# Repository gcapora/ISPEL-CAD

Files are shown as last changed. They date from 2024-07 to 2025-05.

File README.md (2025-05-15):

# Diseño de circuitos impresos del proyecto ISPEL

Autores: Guillermo Caporaletti y Alejandro Santari.
ISPEL Beta, Revisión 1.

En esta carpeta están los diseños de las placas del prototipo Beta 2024 de la Interfaz de Señales para Prácticas Educativas de Laboratorio (ISPEL). 

## Estructura de carpetas

- Docs: Incluye documentos de elaboración propia. Incluye listado de materiales.
- Info: Incluye bibliografía, hojas de datos, referencias y demás información que no es elaboración propia.
- PCB_Frente: PCB de botones y leds del frente del gabinete.
- PCB_Principal: PCB principal, sobre la cual va montada la placa Nuleao-144 de STM.

## Versiones

- Primera versión Beta corresponde al diseño presentado como parte del trabajo final de la Carrera de Especialización en Sistemas Embebidos de la FIUBA: [Versión 1 Beta](https://github.com/gcapora/ISPEL-CAD/releases/tag/v1-beta)

## Comentarios

- El diseño en PCB_Principal fue corregido tras construir el primer prototipo.
- Los archivos de PCB_Frente son orientativos y deben ser corregidos.

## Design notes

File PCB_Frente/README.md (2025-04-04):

Esta carpeta tiene el diseño de la placa de botones y leds del frente del gabinete, versión Beta 2024. El diseño es orientativo porque necesita una corrección importante.

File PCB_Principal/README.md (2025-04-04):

Aquí van los archivos del proyecto PLACA PRINCIPAL que incluye:
- Fuente y tensión de referencia
- Amplificadores
- Búferes de entrada
- Señal de prueba

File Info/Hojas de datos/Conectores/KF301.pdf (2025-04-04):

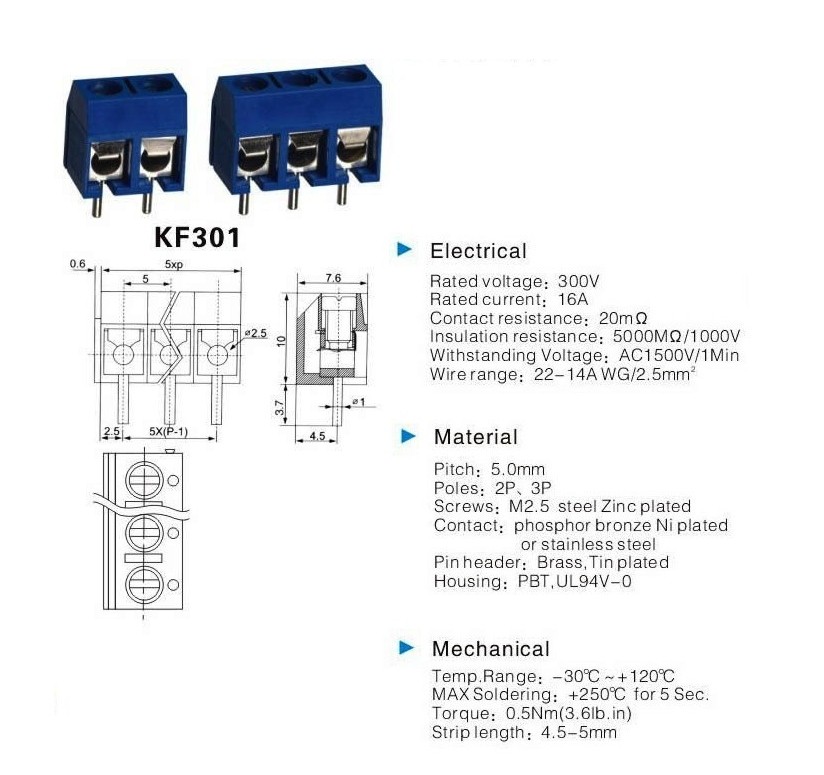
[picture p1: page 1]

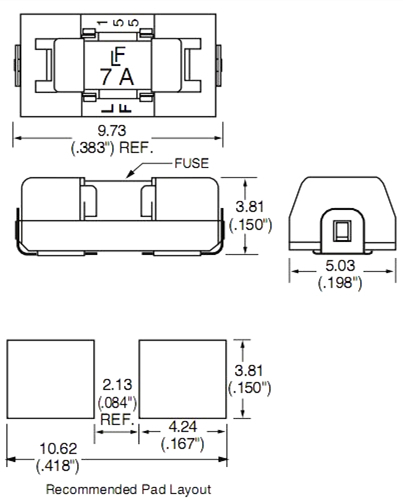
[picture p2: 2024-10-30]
Info/Hojas de datos/Fusibles/Zócalo-1808.webp

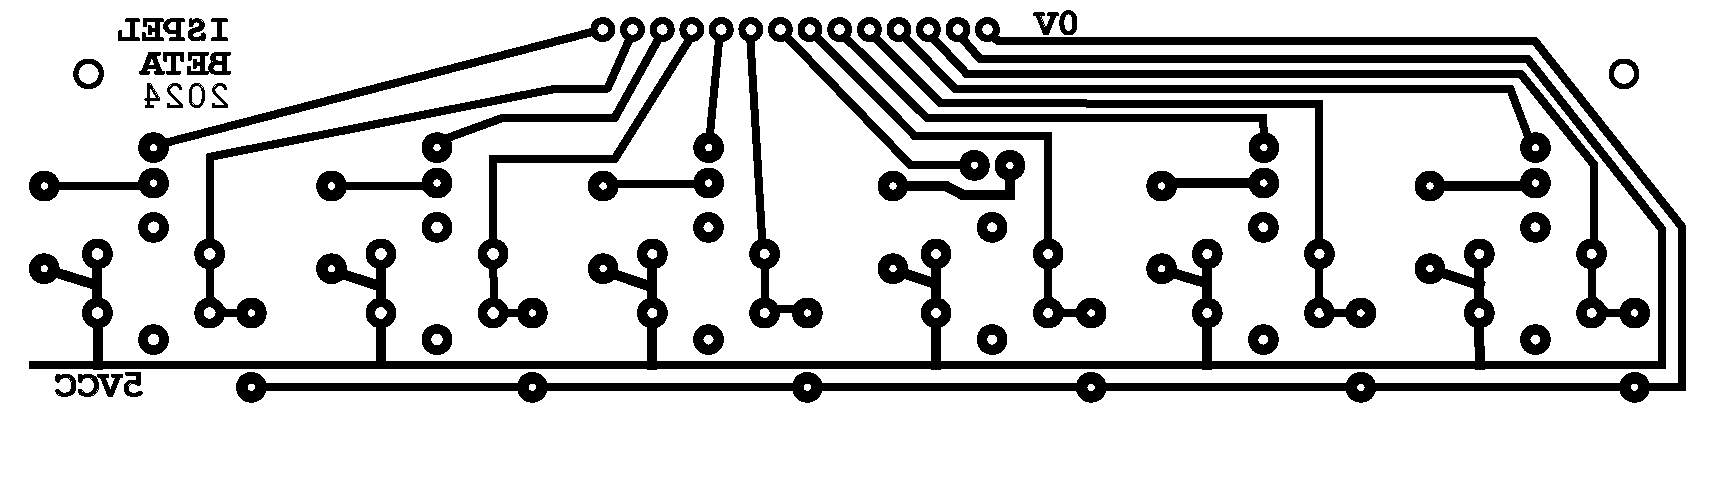
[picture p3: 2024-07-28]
PCB_Frente/frente_gabinete_v3_circuito.png

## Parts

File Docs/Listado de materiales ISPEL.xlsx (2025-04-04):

Reference | Value | Datasheet | Footprint | Qty | DNP
C1,C2 | 6900uF | ~ | Capacitor_THT:CP_Radial_D18.0mm_P7.50mm | 2
C101,C151,C203,C253 | 10pF | ~ | Capacitor_SMD:C_1206_3216Metric_Pad1.33x1.80mm_HandSolder | 4
C102,C152 | 5pF | ~ | Capacitor_SMD:C_1206_3216Metric_Pad1.33x1.80mm_HandSolder | 2
C202,C252 | 100pF | ~ | Capacitor_SMD:C_1206_3216Metric_Pad1.33x1.80mm_HandSolder | 2
C3,C4,C103,C104,C105,C153,C154,C155,C201,C204,C205,C206,C207,C251,C254,C255,C256,C257,C301 | 220nF | ~ | Capacitor_SMD:C_1206_3216Metric_Pad1.33x1.80mm_HandSolder | 19
C5,C6,C7,C8 | 1uF | ~ | Capacitor_SMD:C_1206_3216Metric_Pad1.33x1.80mm_HandSolder | 4
D1 | B40R | https://diotec.com/tl_files/diotec/files/pdf/datasheets/b40r.pdf | Diode_THT:Diode_Bridge_Round_D9.0mm | 1
D101,D102,D151,D152,D201,D202,D251,D252 | 1N4148 | https://assets.nexperia.com/documents/data-sheet/1N4148_1N4448.pdf | Diode_SMD:D_MiniMELF_Handsoldering | 8
D203,D204,D253,D254 | 1N4746A | https://www.vishay.com/docs/85816/1n4728a.pdf | Diode_THT:D_DO-41_SOD81_P10.16mm_Horizontal | 4
F201,F251 | 500mA | ~ | Libreria_ISPEL:Fuseholder_1808_handsoldering | 2
F301 | 250mA | ~ | Libreria_ISPEL:Fuseholder_1808_handsoldering | 1
J1 | Vin | ~ | TerminalBlock_Phoenix:TerminalBlock_Phoenix_MKDS-1,5-3-5.08_1x03_P5.08mm_Horizontal | 1
J11 | CN7_NUCLEO | ~ | Libreria_ISPEL:PinSocket_2x10_P2.54mm_Vertical_impar-par | 1
J12 | CN10_NUCLEO | ~ | Libreria_ISPEL:PinSocket_2x17_P2.54mm_Vertical_impar-par | 1
J14 | E1 | ~ | Connector_Molex:Molex_KK-254_AE-6410-02A_1x02_P2.54mm_Vertical | 1
J15 | S1 | ~ | Connector_Molex:Molex_KK-254_AE-6410-04A_1x04_P2.54mm_Vertical | 1
J16 | E2 | ~ | Connector_Molex:Molex_KK-254_AE-6410-02A_1x02_P2.54mm_Vertical | 1
J17 | S2 | ~ | Connector_Molex:Molex_KK-254_AE-6410-04A_1x04_P2.54mm_Vertical | 1
J18 | FRENTE | ~ | Connector_IDC:IDC-Header_2x10_P2.54mm_Vertical | 1
J19 | PRUEBA_5V | ~ | Connector_Molex:Molex_KK-254_AE-6410-02A_1x02_P2.54mm_Vertical | 1
J2 | V7 | ~ | Connector_PinSocket_2.54mm:PinSocket_1x02_P2.54mm_Vertical | 1
J3 | TEMP | ~ | Connector_PinHeader_2.54mm:PinHeader_1x02_P2.54mm_Vertical | 1
J4 | VREG | ~ | Connector_PinSocket_2.54mm:PinSocket_1x04_P2.54mm_Vertical | 1
J5 | V5 | ~ | Connector_PinSocket_2.54mm:PinSocket_1x02_P2.54mm_Vertical | 1
J6,J9,J10,J13 | GND_NUCLEO | ~ | Connector_PinSocket_2.54mm:PinSocket_1x02_P2.54mm_Vertical | 4
J7 | CN8_NUCLEO | ~ | Libreria_ISPEL:PinSocket_2x08_P2.54mm_Vertical_impar-par | 1
J8 | CN9_NUCLEO | ~ | Libreria_ISPEL:PinSocket_2x15_P2.54mm_Vertical_impar-par | 1
Q201,Q251 | BC807 | https://www.onsemi.com/pub/Collateral/BC808-D.pdf | Package_TO_SOT_SMD:SOT-23 | 2
Q202,Q205,Q252,Q255 | BC559C | https://www.onsemi.com/pub/Collateral/BC556BTA-D.pdf | Package_TO_SOT_THT:TO-92_Inline | 4
Q203,Q204,Q253,Q254 | BC549C | https://www.onsemi.com/pub/Collateral/BC550-D.pdf | Package_TO_SOT_THT:TO-92_Inline | 4
Q206,Q256 | 2SD882 | https://github.com/gcapora/ISPEL-CAD/blob/main/Info/Hojas%20de%20datos/Transistores/2SD882_NEC.pdf | Package_TO_SOT_THT:TO-126-3_Vertical | 2
Q207,Q257 | 2SB772 | https://github.com/gcapora/ISPEL-CAD/blob/main/Info/Hojas%20de%20datos/Transistores/2SB772_NEC.pdf | Package_TO_SOT_THT:TO-126-3_Vertical | 2
R1,R4,R9 | 150 | ~ | Resistor_SMD:R_1206_3216Metric_Pad1.30x1.75mm_HandSolder | 3
R10 | 330 | ~ | Resistor_SMD:R_1206_3216Metric_Pad1.30x1.75mm_HandSolder | 1
R101,R151 | 560K | ~ | Resistor_SMD:R_1206_3216Metric_Pad1.30x1.75mm_HandSolder | 2
R102,R152 | 47K | ~ | Resistor_SMD:R_1206_3216Metric_Pad1.30x1.75mm_HandSolder | 2
R103,R153 | 390K | ~ | Resistor_SMD:R_1206_3216Metric_Pad1.30x1.75mm_HandSolder | 2
R104,R105,R106,R107,R108,R154,R155,R156,R157,R158,R202,R205,R206,R210,R220,R252,R255,R256,R260,R270,R301,R302,R303 | 10K | ~ | Resistor_SMD:R_1206_3216Metric_Pad1.30x1.75mm_HandSolder | 23
R11 | 1K5 | ~ | Resistor_SMD:R_1206_3216Metric_Pad1.30x1.75mm_HandSolder | 1
R12,R13,R203,R204,R253,R254 | 4K7 | ~ | Resistor_SMD:R_1206_3216Metric_Pad1.30x1.75mm_HandSolder | 6
R14,R15,RT1,RT2,RT3,RT4,RT5 | 0.1 | ~ | Resistor_SMD:R_1206_3216Metric_Pad1.30x1.75mm_HandSolder | 7
R2,R7 | 1K2 | ~ | Resistor_SMD:R_1206_3216Metric_Pad1.30x1.75mm_HandSolder | 2
R201,R207,R209,R211,R251,R257,R259,R261 | 1K | ~ | Resistor_SMD:R_1206_3216Metric_Pad1.30x1.75mm_HandSolder | 8
R208,R258 | 100K | ~ | Resistor_SMD:R_1206_3216Metric_Pad1.30x1.75mm_HandSolder | 2
R212,R213,R262,R263 | 33 | ~ | Resistor_SMD:R_1206_3216Metric_Pad1.30x1.75mm_HandSolder | 4
R214,R215,R264,R265 | 1.5 | ~ | Resistor_THT:R_Axial_DIN0309_L9.0mm_D3.2mm_P12.70mm_Horizontal | 4
R216,R217,R266,R267 | CAL | ~ | Resistor_SMD:R_1206_3216Metric_Pad1.30x1.75mm_HandSolder | 4
R218,R219,R268,R269 | 100_2W | ~ | Resistor_THT:R_Axial_DIN0414_L11.9mm_D4.5mm_P15.24mm_Horizontal | 4
R3,R8,R304,R305 | 100 | ~ | Resistor_SMD:R_1206_3216Metric_Pad1.30x1.75mm_HandSolder | 4
R5 | 150K | ~ | Resistor_SMD:R_1206_3216Metric_Pad1.30x1.75mm_HandSolder | 1
R6 | 690 | ~ | Resistor_SMD:R_1206_3216Metric_Pad1.30x1.75mm_HandSolder | 1
RV101,RV151,RV201,RV251 | Evm3eSX50b102 | https://github.com/gcapora/ISPEL-CAD/blob/main/Info/Hojas%20de%20datos/Resistencias/EVM-3RSX50B54.PDF | Libreria_ISPEL:3E-SX50 | 4
U1,U2 | LM350_TO220 | https://www.onsemi.com/pub/Collateral/LM350-D.pdf | Package_TO_SOT_THT:TO-220-3_Vertical | 2
U101,U151 | CA3140 | https://www.renesas.com/en/document/dst/ca3140-ca3140a-datasheet?r=505296 | Package_DIP:CERDIP-8_W7.62mm_SideBrazed_LongPads_Socket | 2
U201,U251 | LM318 | http://www.ti.com/lit/ds/symlink/lm318-n.pdf | Package_DIP:CERDIP-8_W7.62mm_SideBrazed_LongPads_Socket | 2
U3 | LM337_TO220 | http://www.ti.com/lit/ds/symlink/lm337-n.pdf | Package_TO_SOT_THT:TO-220-3_Vertical | 1
U301 | TLV3501AID | https://www.ti.com/lit/ds/symlink/tlv3501.pdf | Package_SO:SOIC-8_3.9x4.9mm_P1.27mm | 1
U4 | LM1117DT-5.0 | http://www.ti.com/lit/ds/symlink/lm1117.pdf | Package_TO_SOT_SMD:TO-252-3_TabPin2 | 1
U5 | TL431DBZ | http://www.ti.com/lit/ds/symlink/tl431.pdf | Package_TO_SOT_SMD:SOT-23 | 1

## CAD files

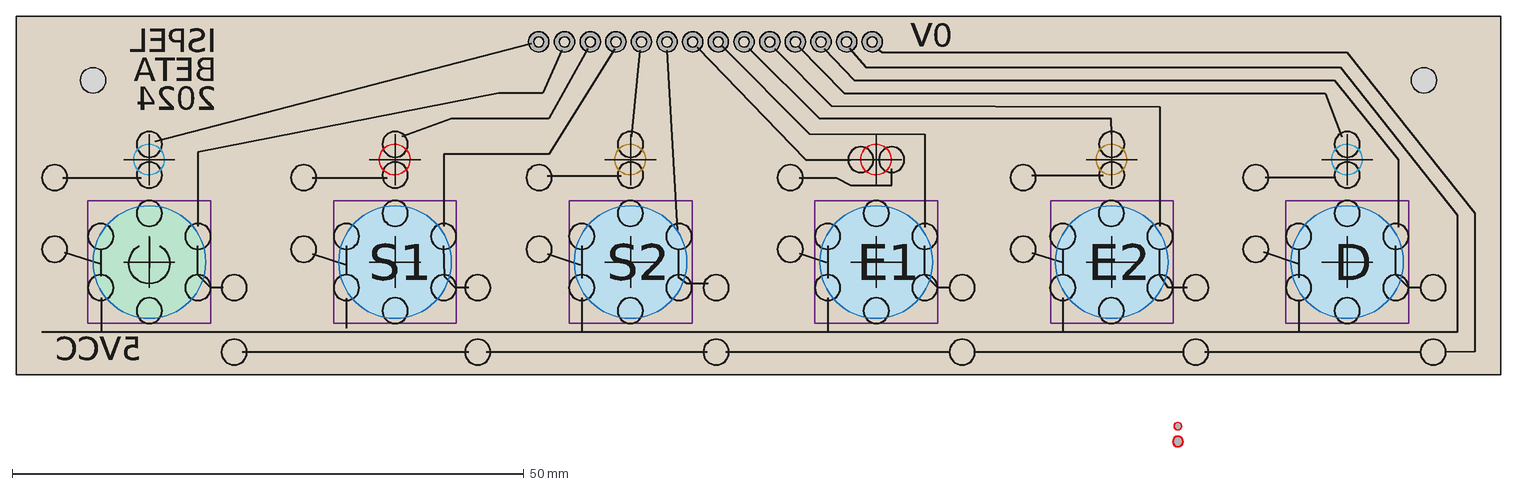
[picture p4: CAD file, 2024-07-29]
PCB_Frente/frente_gabinete_v3_circuito.dxf
0V
5VCC
ISPEL
BETA
2024
S1
S2
E1
E2
D

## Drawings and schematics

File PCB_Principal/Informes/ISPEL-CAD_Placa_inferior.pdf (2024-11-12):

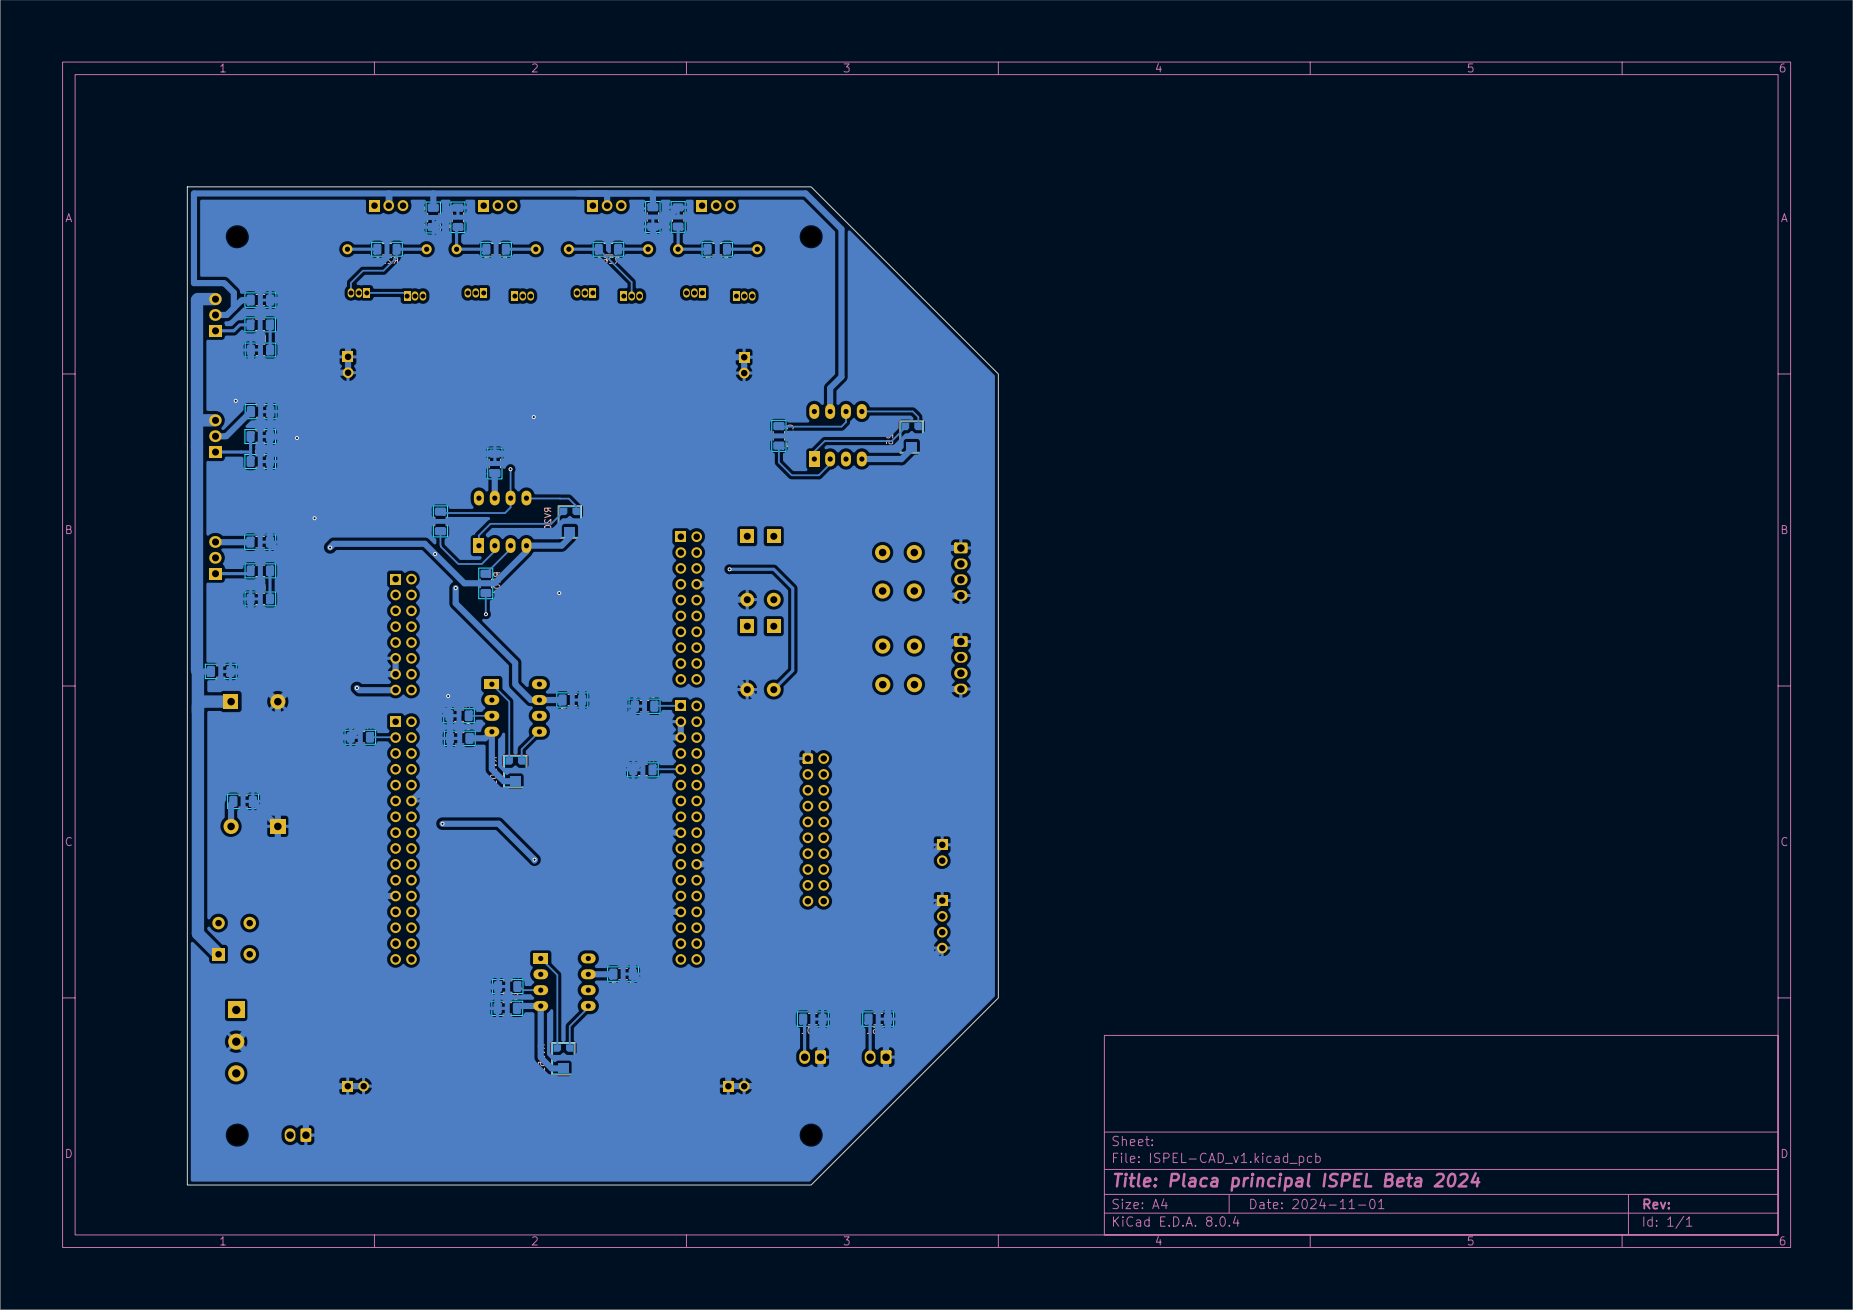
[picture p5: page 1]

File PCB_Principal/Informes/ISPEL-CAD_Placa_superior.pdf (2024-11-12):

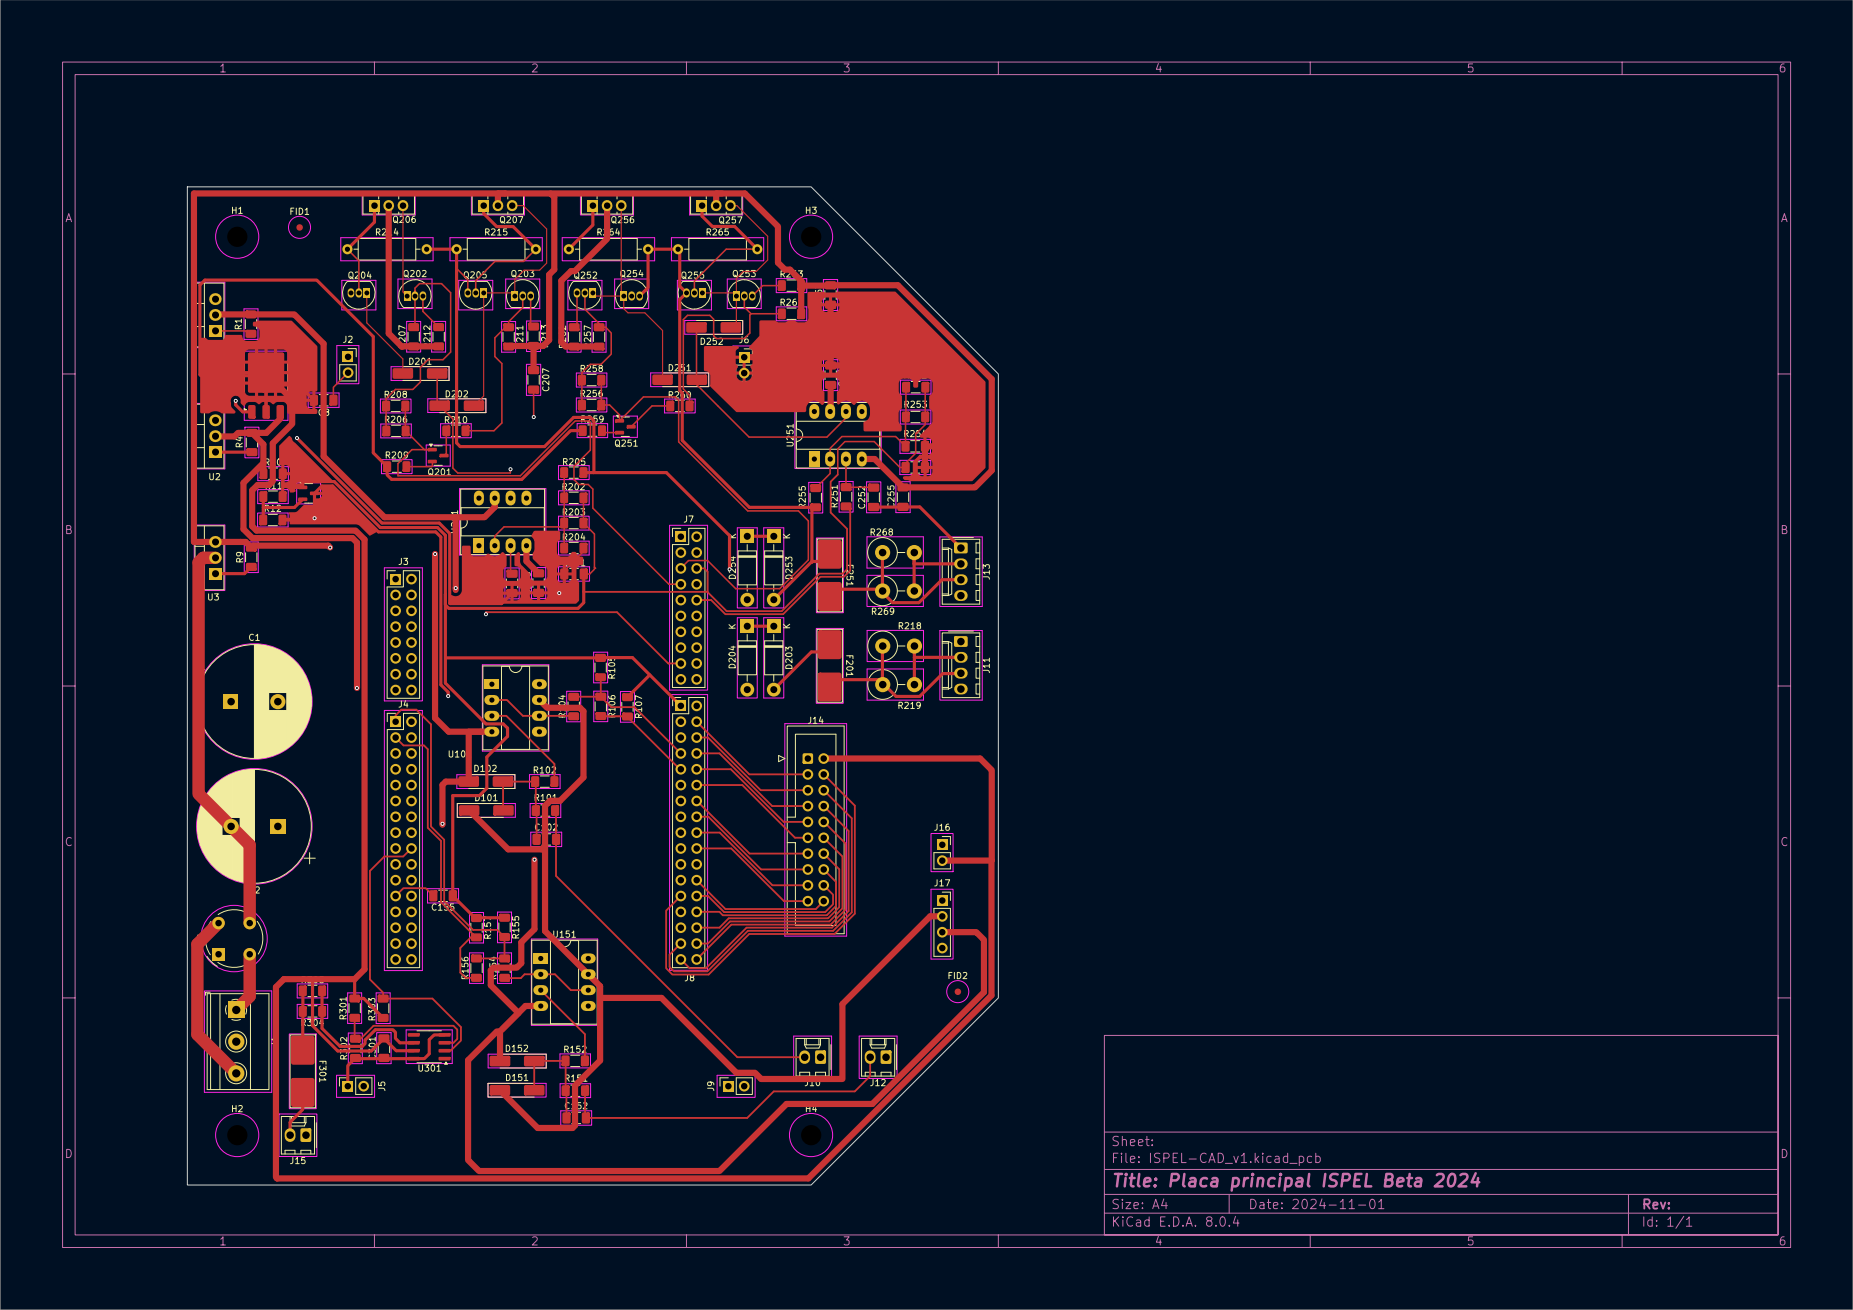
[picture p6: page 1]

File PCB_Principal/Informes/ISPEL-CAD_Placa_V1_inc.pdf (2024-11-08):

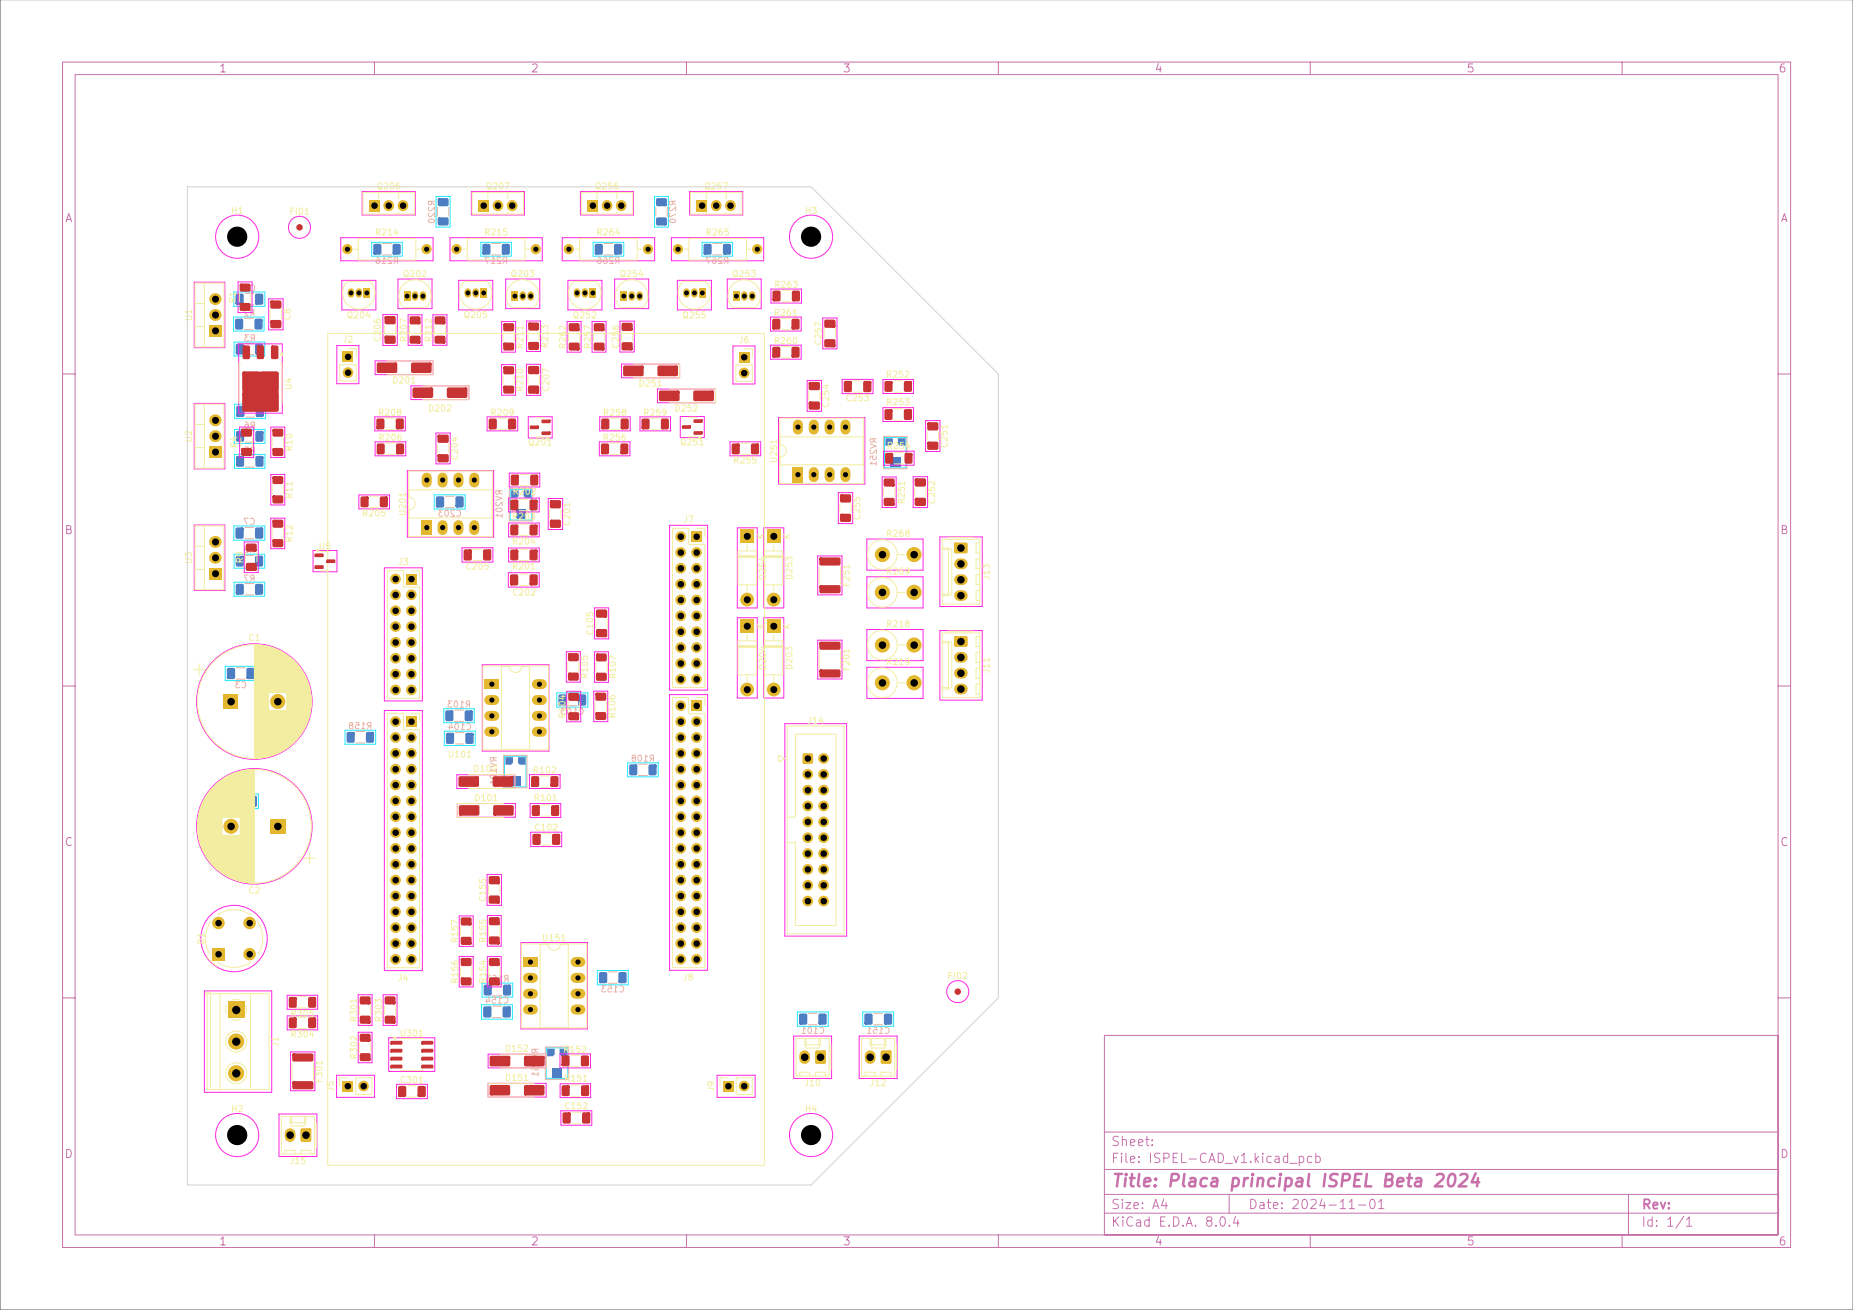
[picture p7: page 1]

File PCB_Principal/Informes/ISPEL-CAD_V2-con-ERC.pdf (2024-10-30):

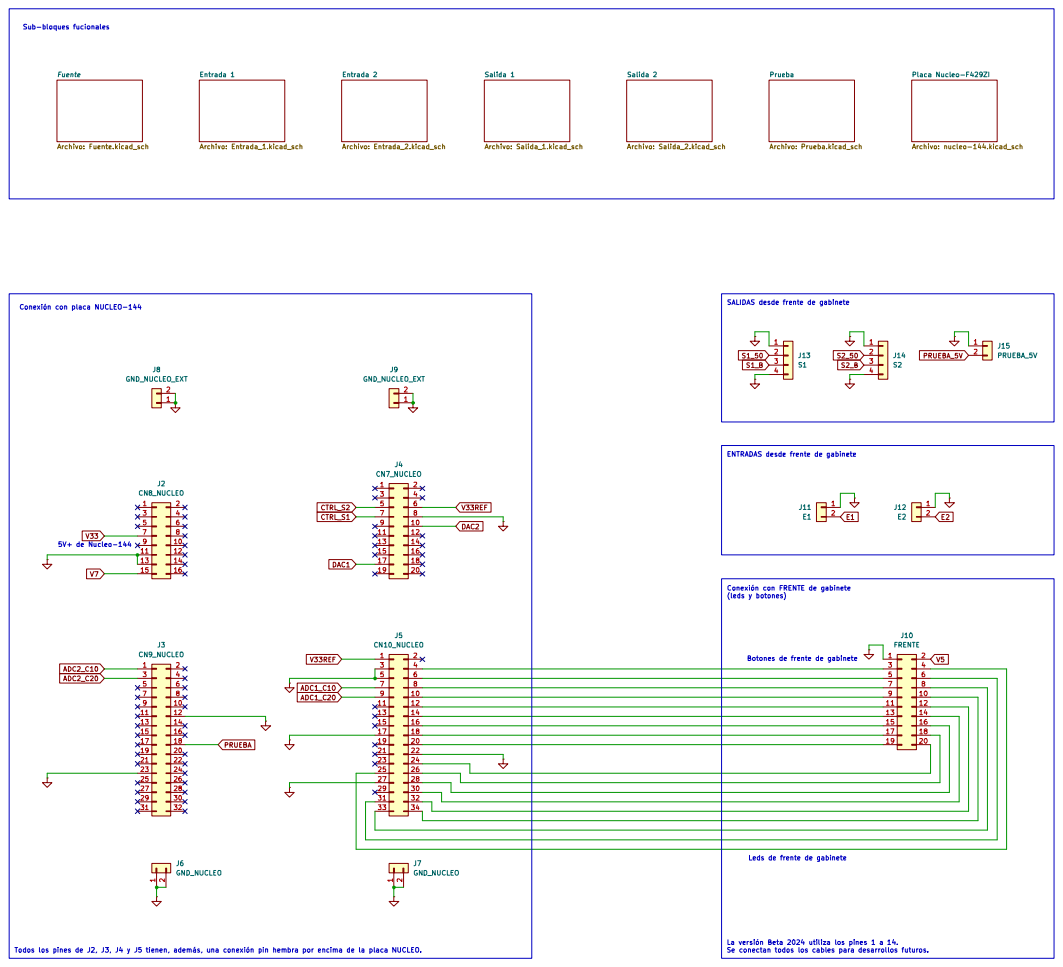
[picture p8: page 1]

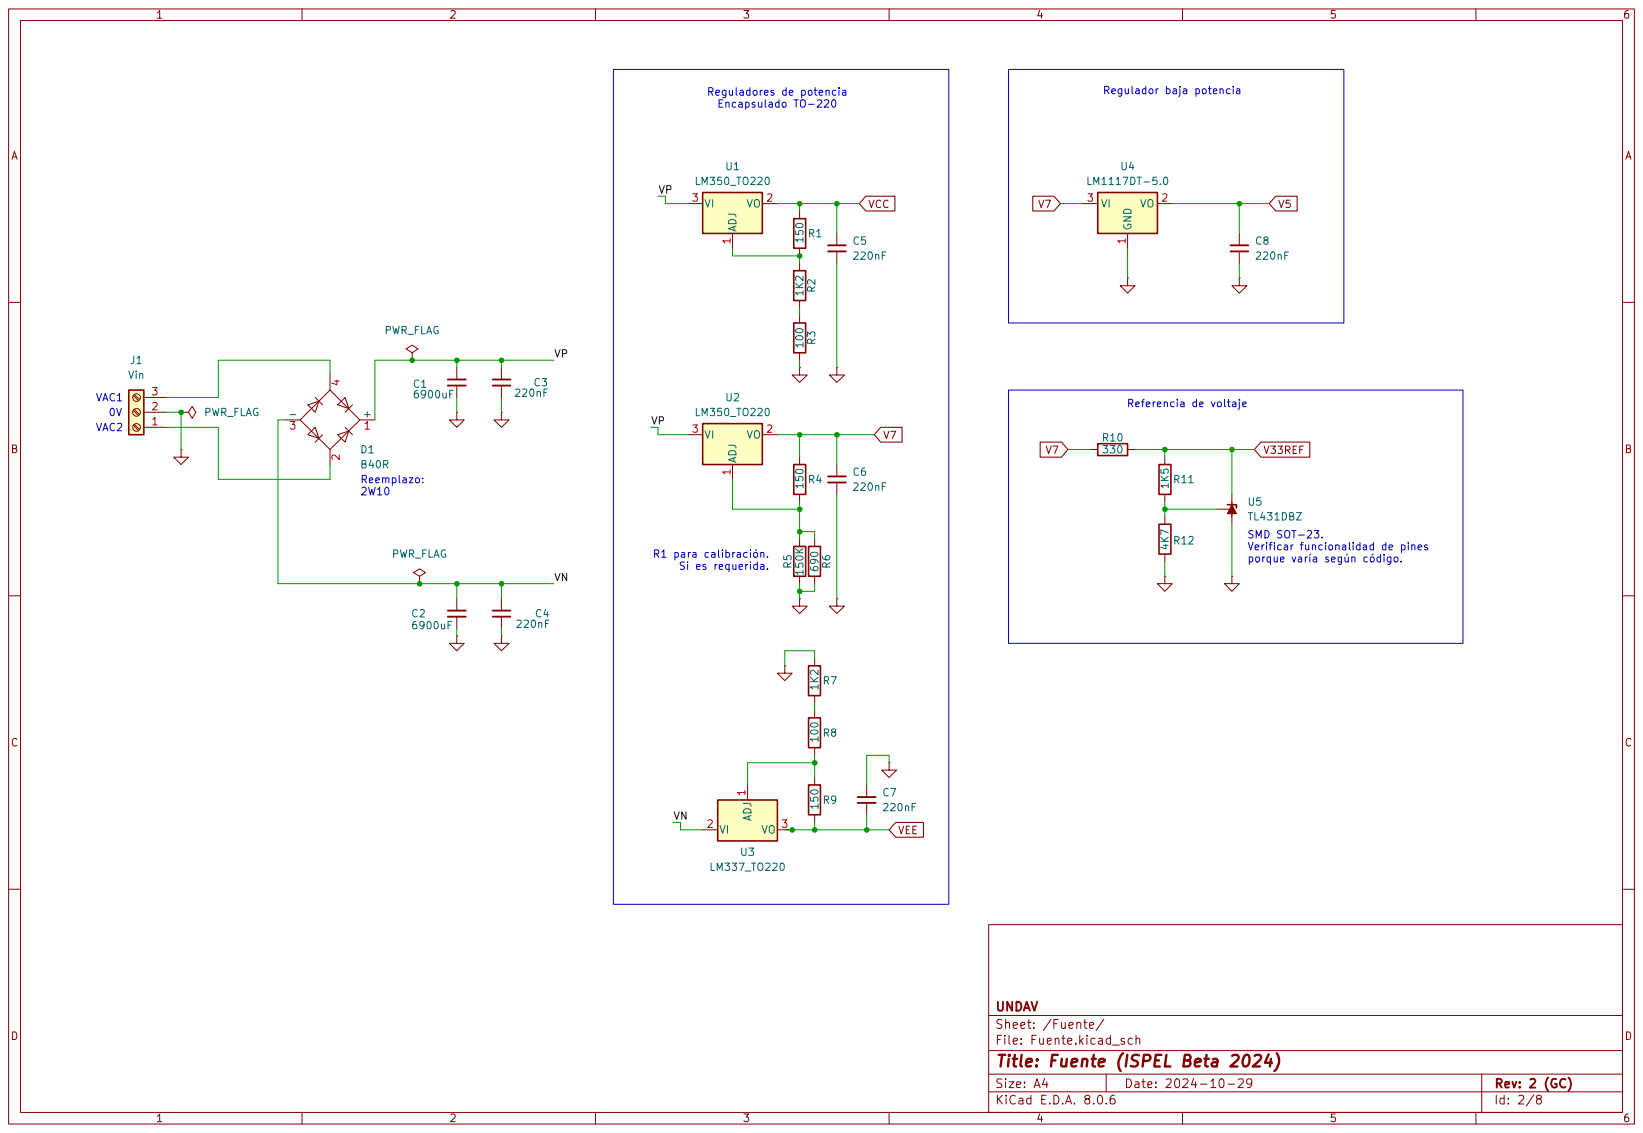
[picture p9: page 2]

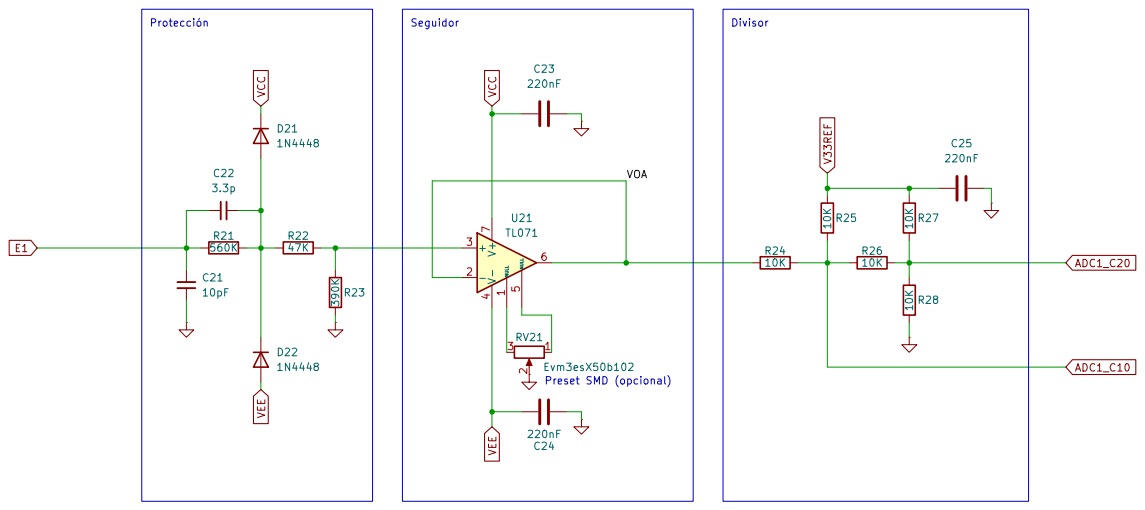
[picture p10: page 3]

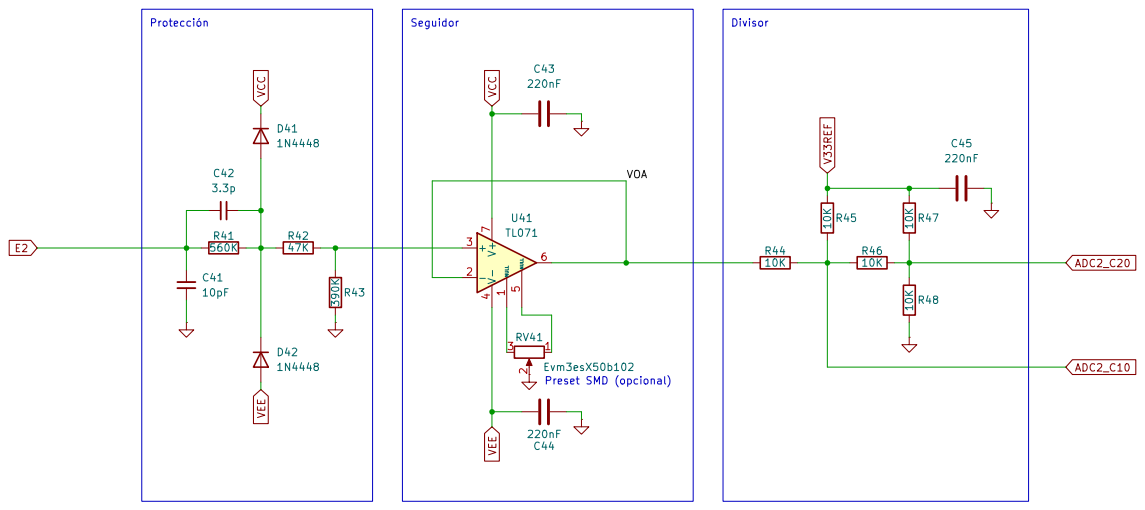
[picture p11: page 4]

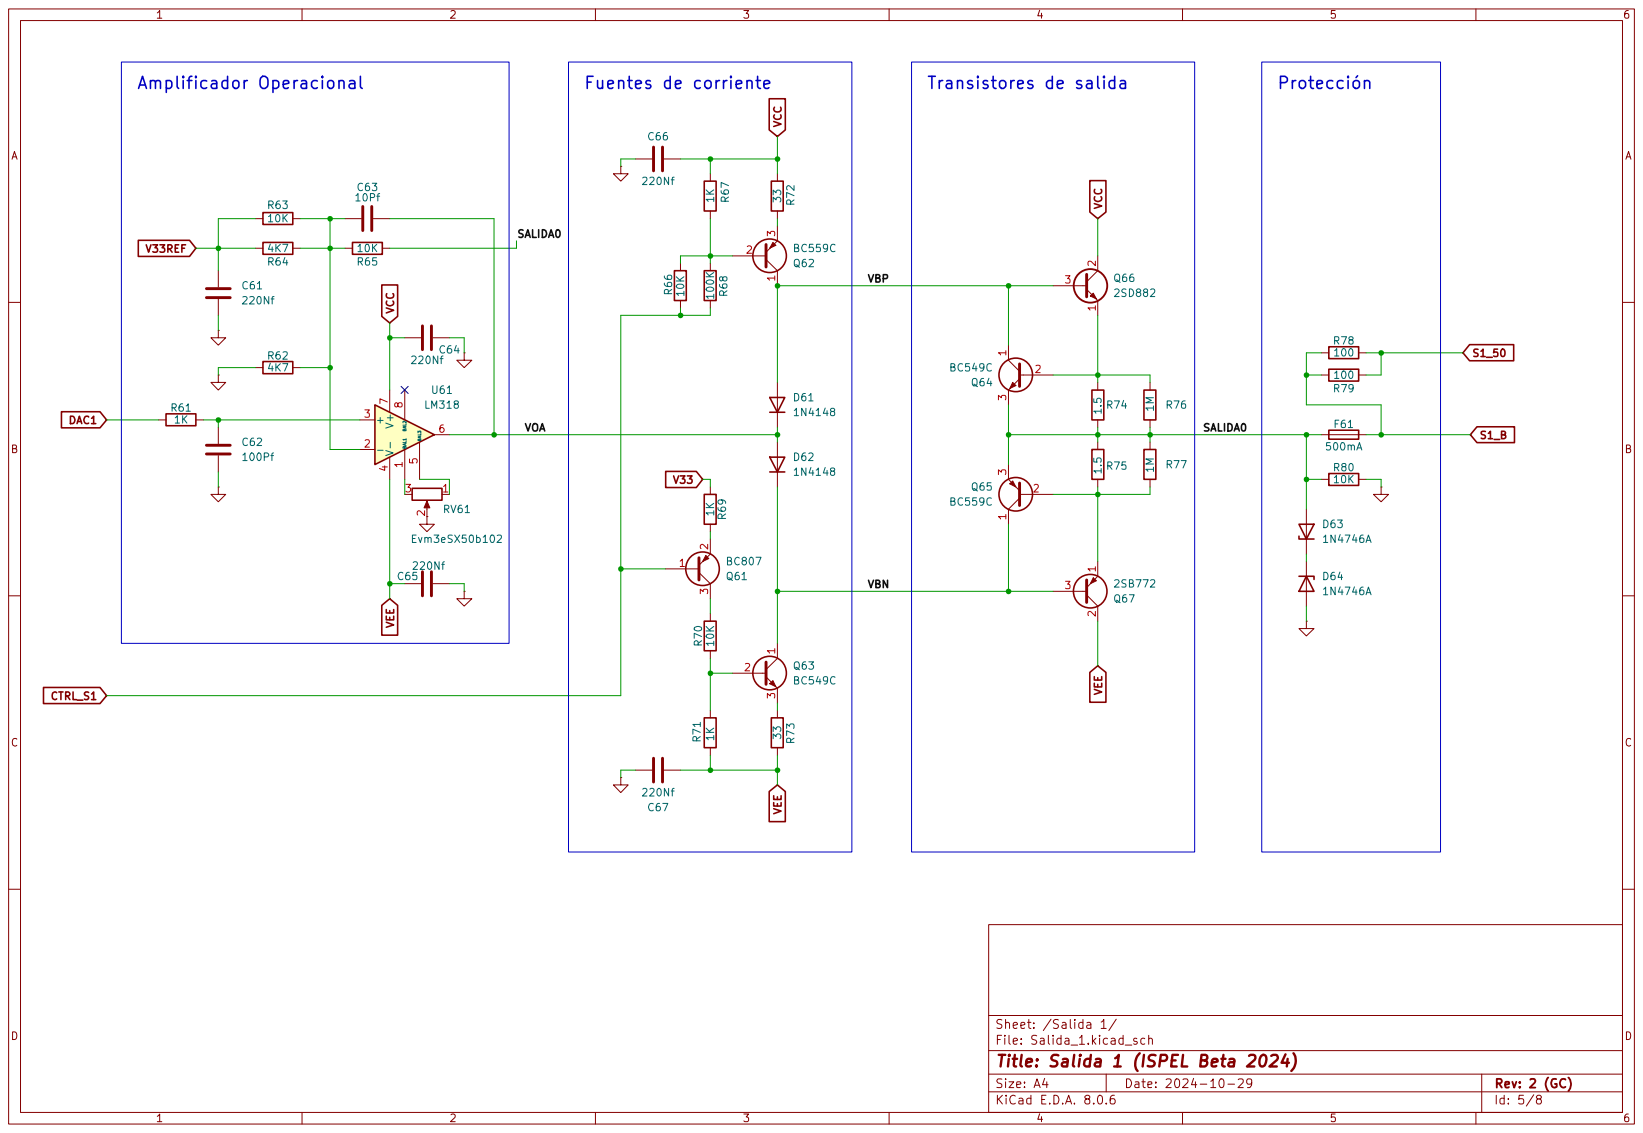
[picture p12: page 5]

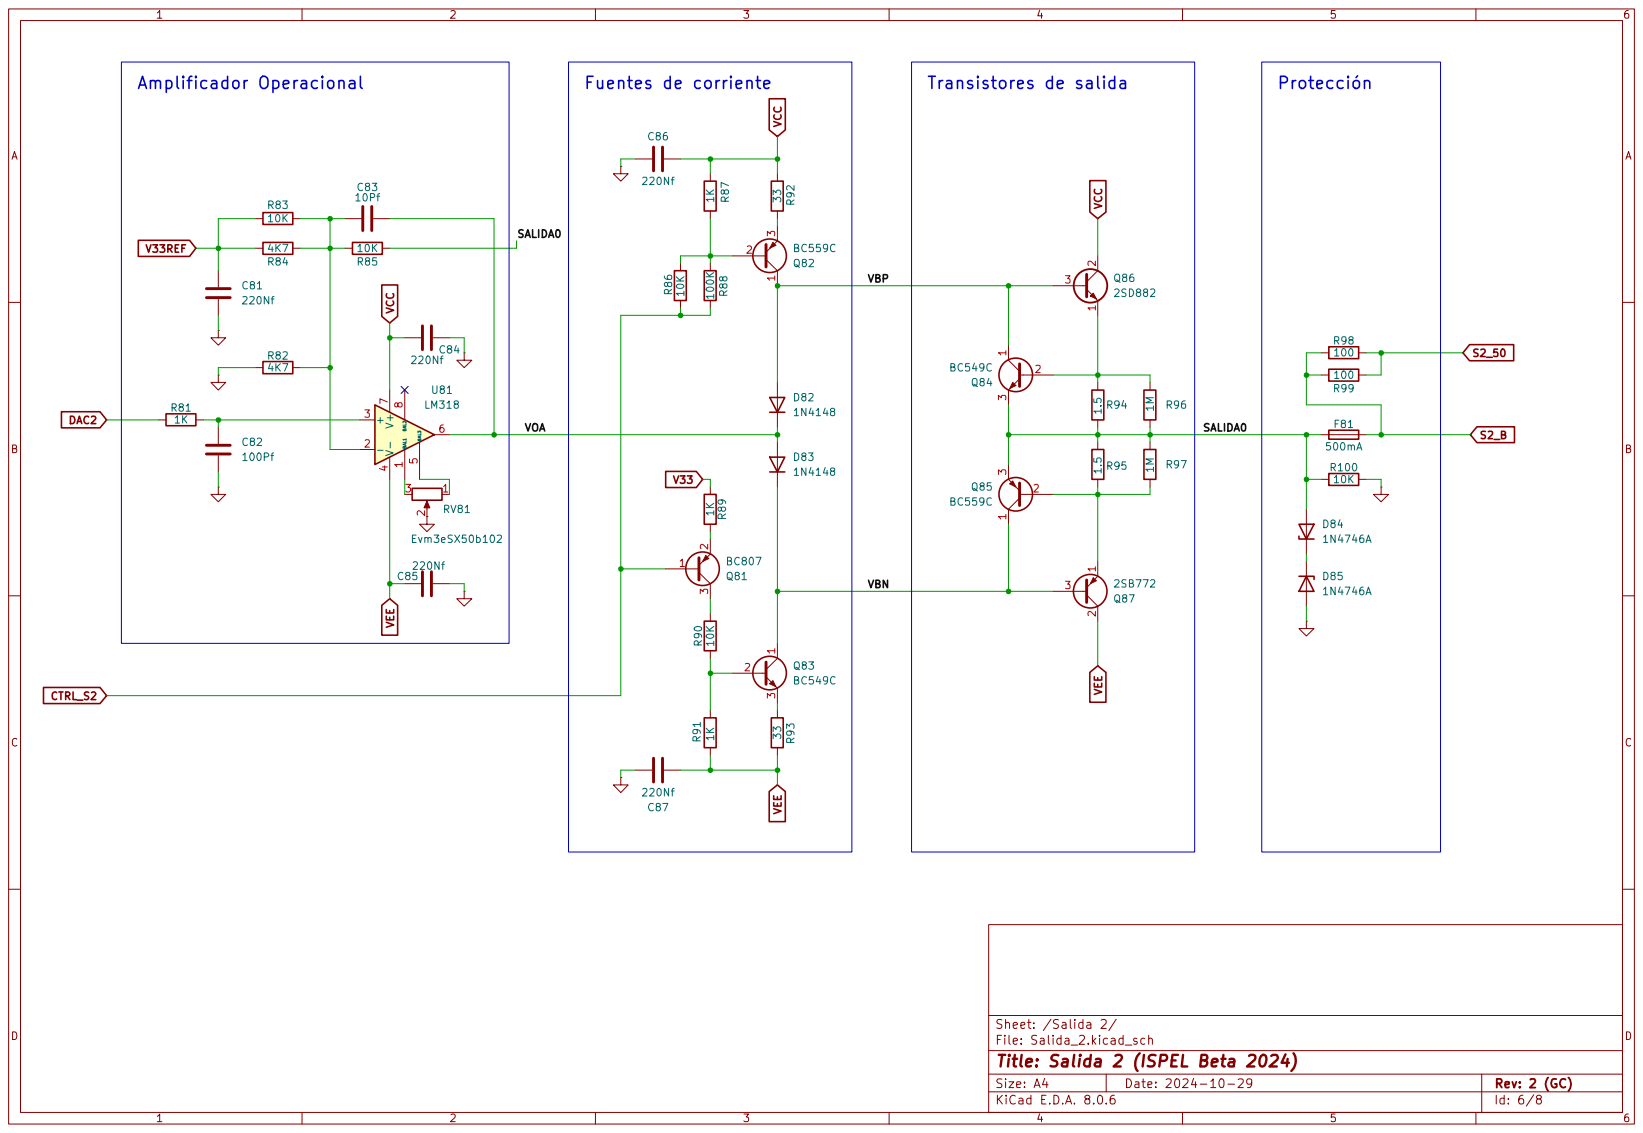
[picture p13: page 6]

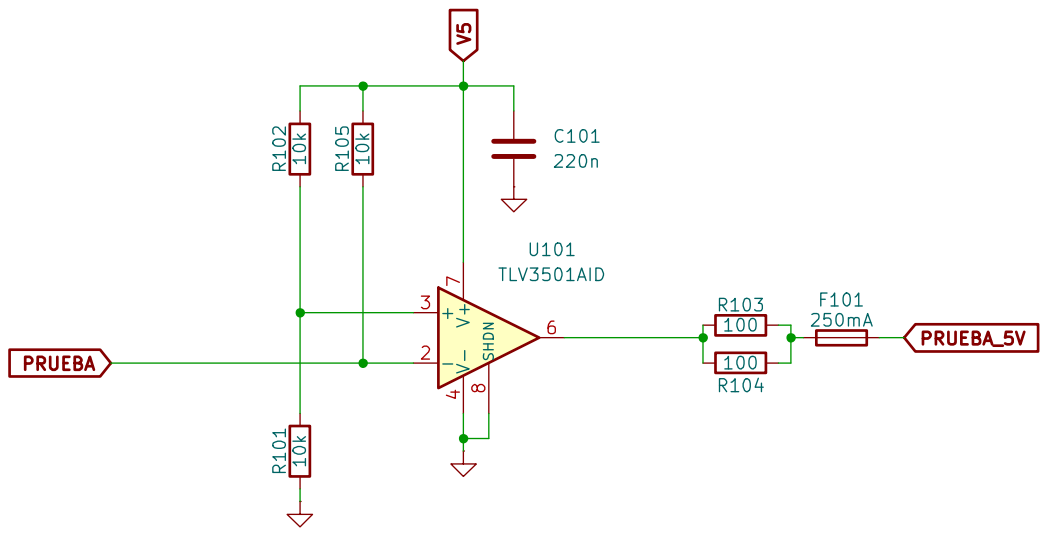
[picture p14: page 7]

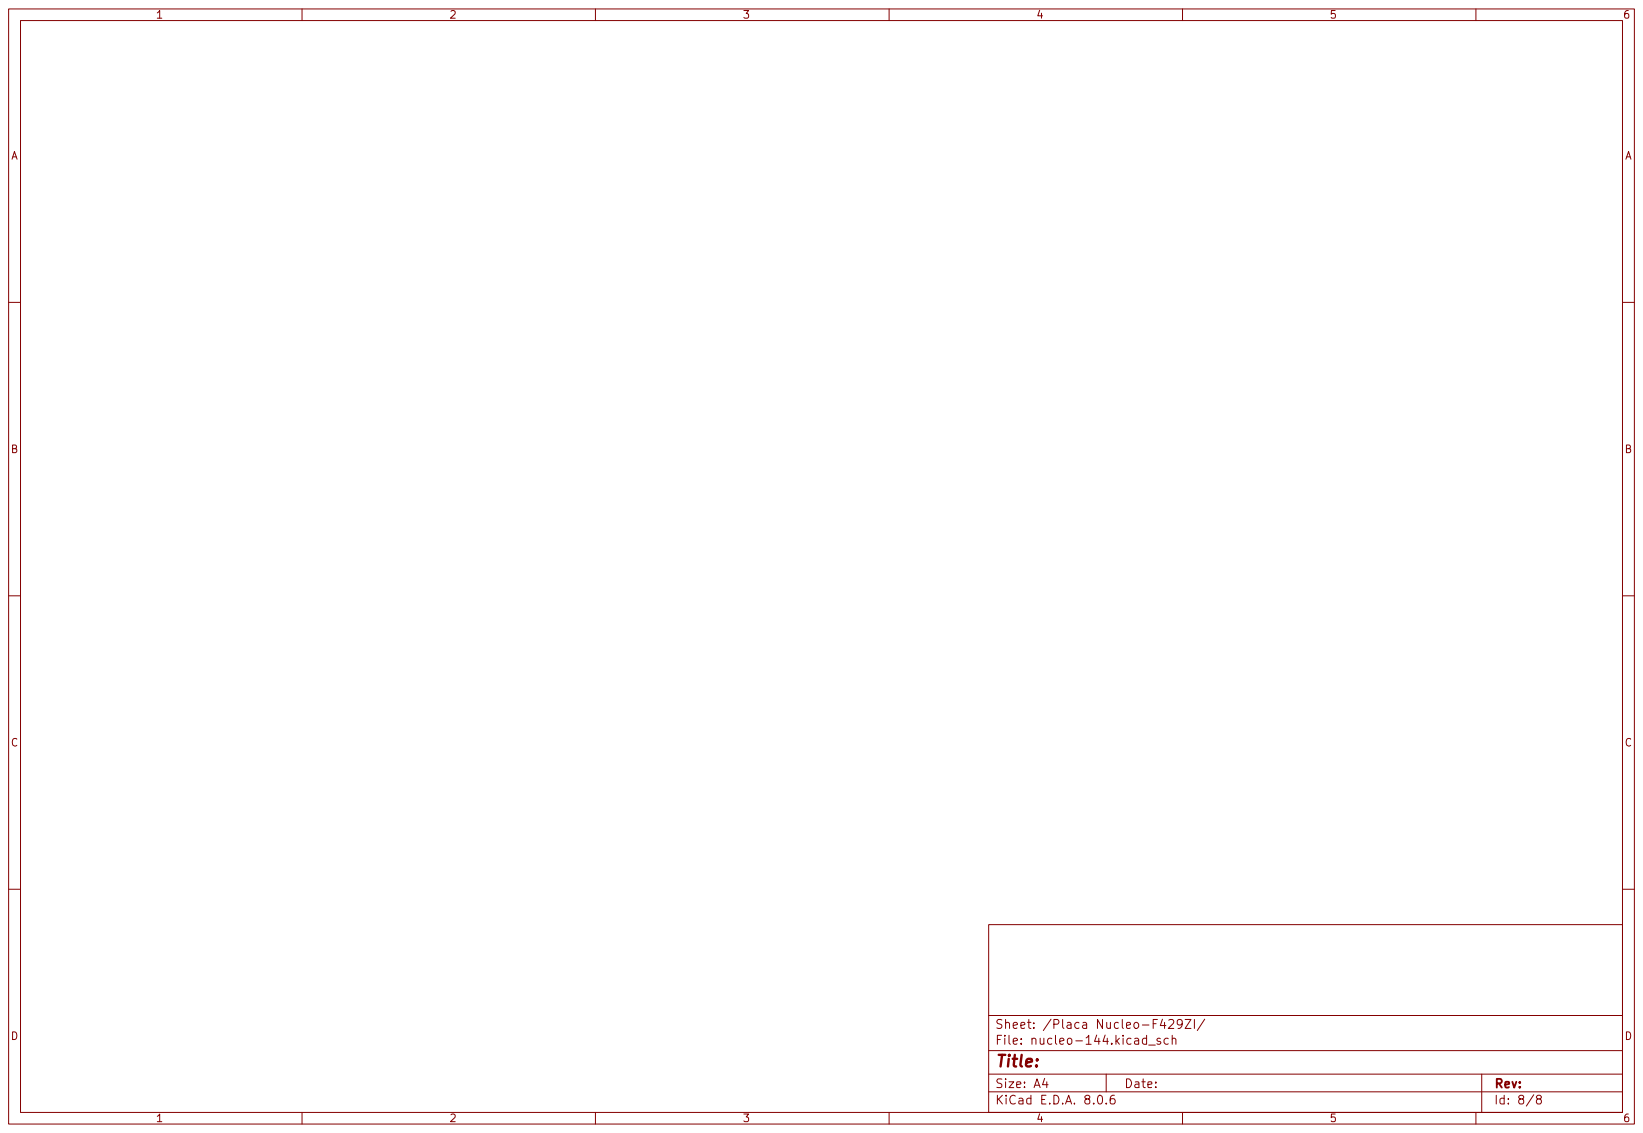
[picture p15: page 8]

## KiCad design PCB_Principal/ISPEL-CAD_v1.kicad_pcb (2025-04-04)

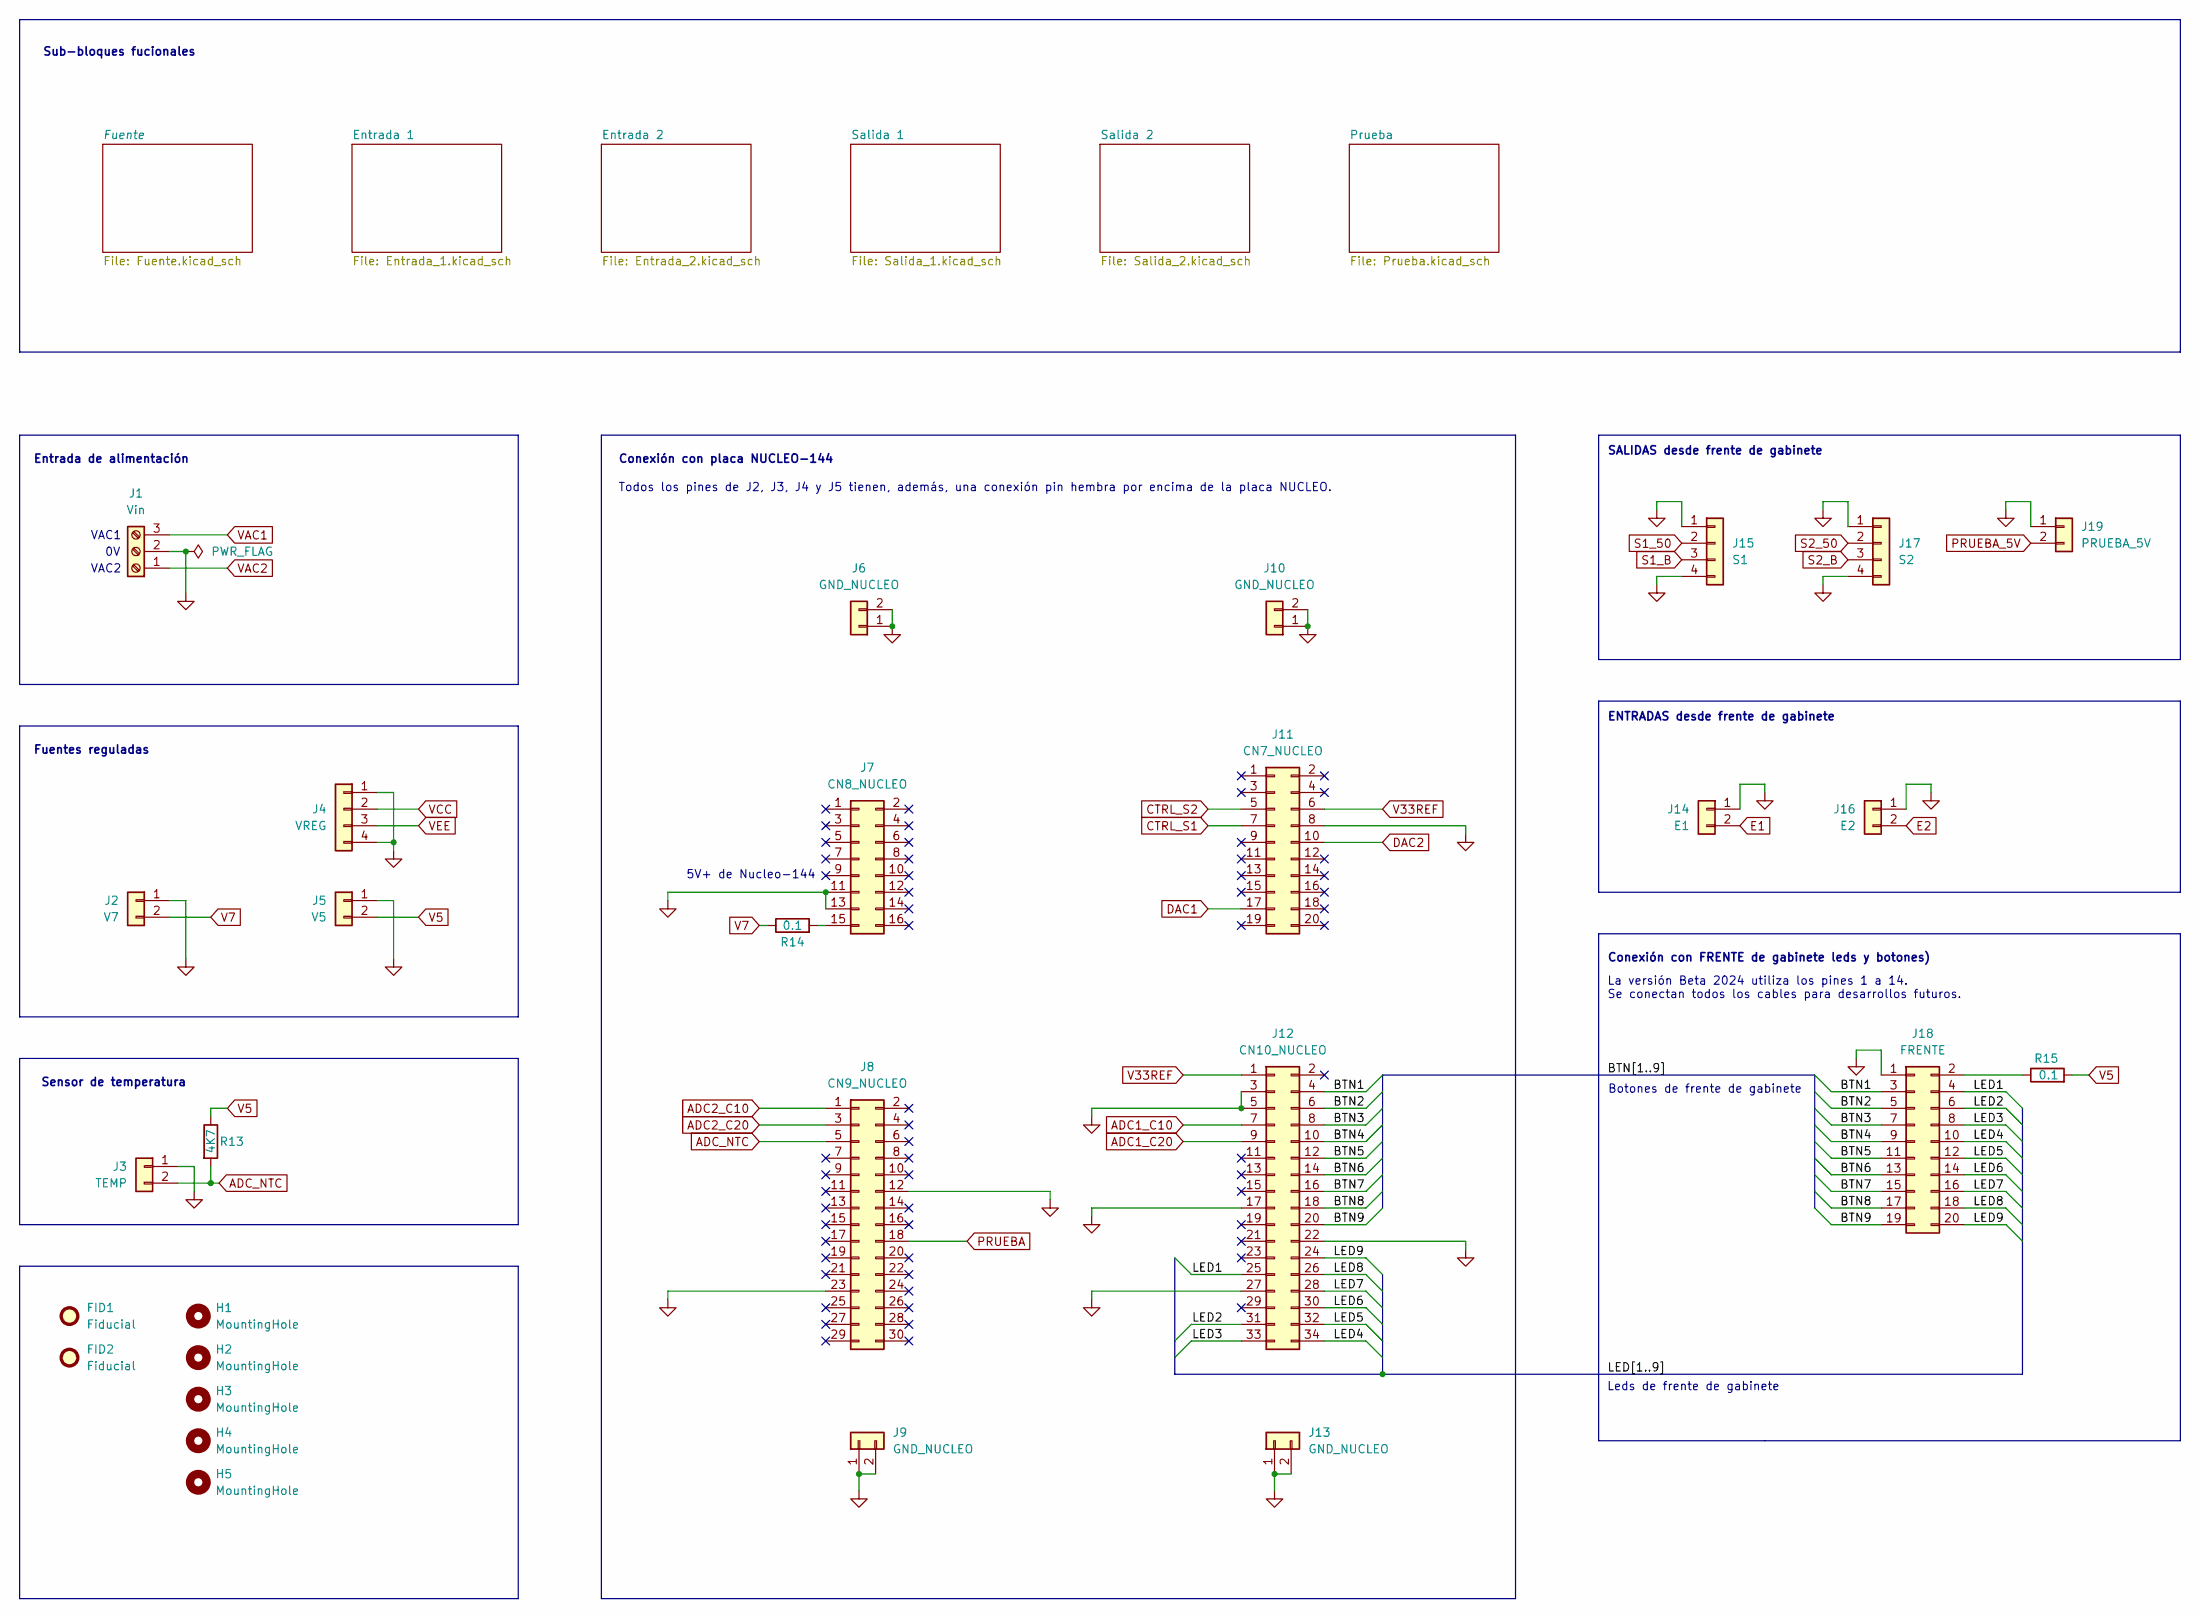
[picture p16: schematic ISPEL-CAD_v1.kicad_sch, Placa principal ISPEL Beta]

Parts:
FID1, FID2: Fiducial; Fiducial_1mm_Mask3mm
H1, H2, H3, H4, H5: MountingHole; MountingHole_3.2mm_M3
J1: Vin; TerminalBlock_Phoenix_MKDS-1,5-3-5.08_1x03_P5.08mm_Horizont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
J2: V7; PinSocket_1x02_P2.54mm_Vertical
J3: TEMP; PinHeader_1x02_P2.54mm_Vertical
J4: VREG; PinSocket_1x04_P2.54mm_Vertical
J5: V5; PinSocket_1x02_P2.54mm_Vertical
J6, J9, J10, J13: GND_NUCLEO; PinSocket_1x02_P2.54mm_Vertical
J7: CN8_NUCLEO; PinSocket_2x08_P2.54mm_Vertical_impar-par
J8: CN9_NUCLEO; PinSocket_2x15_P2.54mm_Vertical_impar-par
J11: CN7_NUCLEO; PinSocket_2x10_P2.54mm_Vertical_impar-par
J12: CN10_NUCLEO; PinSocket_2x17_P2.54mm_Vertical_impar-par
J14: E1; Molex_KK-254_AE-6410-02A_1x02_P2.54mm_Vertical
J15: S1; Molex_KK-254_AE-6410-04A_1x04_P2.54mm_Vertical
J16: E2; Molex_KK-254_AE-6410-02A_1x02_P2.54mm_Vertical
J17: S2; Molex_KK-254_AE-6410-04A_1x04_P2.54mm_Vertical
J18: FRENTE; IDC-Header_2x10_P2.54mm_Vertical
J19: PRUEBA_5V; Molex_KK-254_AE-6410-02A_1x02_P2.54mm_Vertical
R13: 4K7; R_1206_3216Metric_Pad1.30x1.75mm_HandSolder
R14, R15: 0.1; R_1206_3216Metric_Pad1.30x1.75mm_HandSolder

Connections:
/BTN1: J12.4, J18.3
/BTN2: J12.6, J18.5
/BTN3: J12.8, J18.7
/BTN4: J12.10, J18.9
/BTN5: J12.12, J18.11
/BTN6: J12.14, J18.13
/BTN7: J12.16, J18.15
/BTN8: J12.18, J18.17
/BTN9: J12.20, J18.19
/LED1: J12.25, J18.4
/LED2: J12.31, J18.6
/LED3: J12.33, J18.8
/LED4: J12.34, J18.10
/LED5: J12.32, J18.12
/LED6: J12.30, J18.14
/LED7: J12.28, J18.16
/LED8: J12.26, J18.18
/LED9: J12.24, J18.20
ADC1_C10: J12.7; also elsewhere on the board
ADC1_C20: J12.9; also elsewhere on the board
ADC2_C10: J8.1; also elsewhere on the board
ADC2_C20: J8.3; also elsewhere on the board
ADC_NTC: J3.2, J8.5, R13.2
CTRL_S1: J11.7; also elsewhere on the board
CTRL_S2: J11.5; also elsewhere on the board
DAC1: J11.17; also elsewhere on the board
DAC2: J11.10; also elsewhere on the board
E1: J14.2; also elsewhere on the board
E2: J16.2; also elsewhere on the board
GND: J1.2, J2.1, J3.1, J4.1, J4.4, J5.1, J6.1, J6.2, J7.11, J7.13, J8.12, J8.23, J9.1, J9.2, J10.1, J10.2, J11.8, J12.3, J12.5, J12.17, J12.22, J12.27, J13.1, J13.2, J14.1, J15.1, J15.4, J16.1, J17.1, J17.4, J18.1, J19.1; also elsewhere on the board
unnamed: J7.15, R14.2
unnamed: J18.2, R15.1
PRUEBA: J8.18; also elsewhere on the board
PRUEBA_5V: J19.2; also elsewhere on the board
S1_50: J15.2; also elsewhere on the board
S1_B: J15.3; also elsewhere on the board
S2_50: J17.2; also elsewhere on the board
S2_B: J17.3; also elsewhere on the board
V5: J5.2, R13.1, R15.2; also elsewhere on the board
V7: J2.2, R14.1; also elsewhere on the board
V33REF: J11.6, J12.1; also elsewhere on the board
VAC1: J1.3; also elsewhere on the board
VAC2: J1.1; also elsewhere on the board
VCC: J4.2; also elsewhere on the board
VEE: J4.3; also elsewhere on the board

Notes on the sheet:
5V+ de Nucleo-144
Conexión con FRENTE de gabinete leds y botones)
ENTRADAS desde frente de gabinete
Leds de frente de gabinete
VAC1
La versión Beta 2024 utiliza los pines 1 a 14. Se conectan todos los cables para desarrollos futuros.
Fuentes reguladas
Entrada de alimentación
Todos los pines de J2, J3, J4 y J5 tienen, además, una conexión pin hembra por encima de la placa NUCLEO.
Sub-bloques fucionales
Conexión con placa NUCLEO-144
Botones de frente de gabinete
VAC2
SALIDAS desde frente de gabinete
Sensor de temperatura

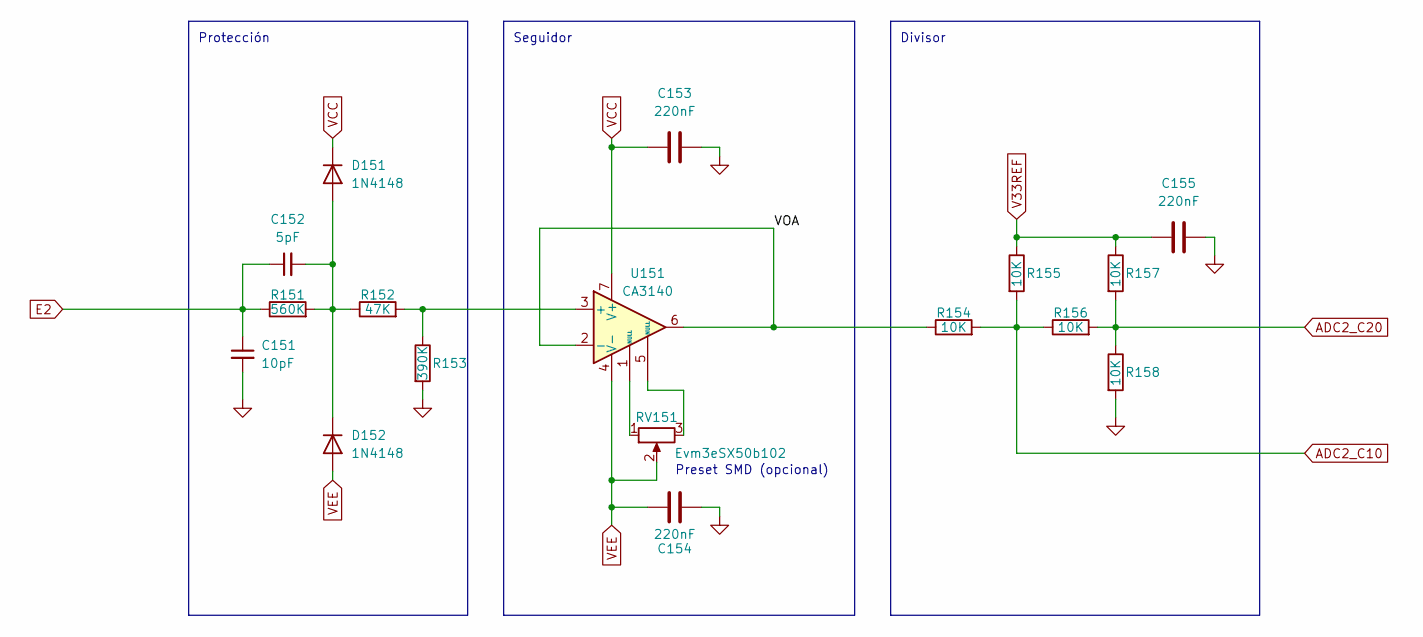
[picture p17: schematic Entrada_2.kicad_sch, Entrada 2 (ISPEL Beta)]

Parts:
C151: 10pF; C_1206_3216Metric_Pad1.33x1.80mm_HandSolder
C152: 5pF; C_1206_3216Metric_Pad1.33x1.80mm_HandSolder
C153, C154, C155: 220nF; C_1206_3216Metric_Pad1.33x1.80mm_HandSolder
D151, D152: 1N4148; D_MiniMELF_Handsoldering
R151: 560K; R_1206_3216Metric_Pad1.30x1.75mm_HandSolder
R152: 47K; R_1206_3216Metric_Pad1.30x1.75mm_HandSolder
R153: 390K; R_1206_3216Metric_Pad1.30x1.75mm_HandSolder
R154, R155, R156, R157, R158: 10K; R_1206_3216Metric_Pad1.30x1.75mm_HandSolder
RV151: Evm3eSX50b102; 3E-SX50
U151: CA3140; CERDIP-8_W7.62mm_SideBrazed_LongPads_Socket

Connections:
/Entrada 2/VOA: R154.1, U151.2 (-), U151.6
ADC2_C10: R154.2, R155.2, R156.1; also elsewhere on the board
ADC2_C20: R156.2, R157.2, R158.1; also elsewhere on the board
E2: C151.1, C152.1, R151.1; also elsewhere on the board
GND: C151.2, C153.2, C154.2, C155.2, R153.2, R158.2; also elsewhere on the board
unnamed: C152.2, D151.2 (A), D152.1 (K), R151.2, R152.1
unnamed: RV151.1, U151.1 (NULL)
unnamed: RV151.3, U151.5 (NULL)
unnamed: R152.2, R153.1, U151.3 (+)
V33REF: C155.1, R155.1, R157.1; also elsewhere on the board
VCC: C153.1, D151.1 (K), U151.7 (V+); also elsewhere on the board
VEE: C154.1, D152.2 (A), RV151.2, U151.4 (V-); also elsewhere on the board

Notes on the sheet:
Preset SMD (opcional)
Protección
Divisor
Seguidor

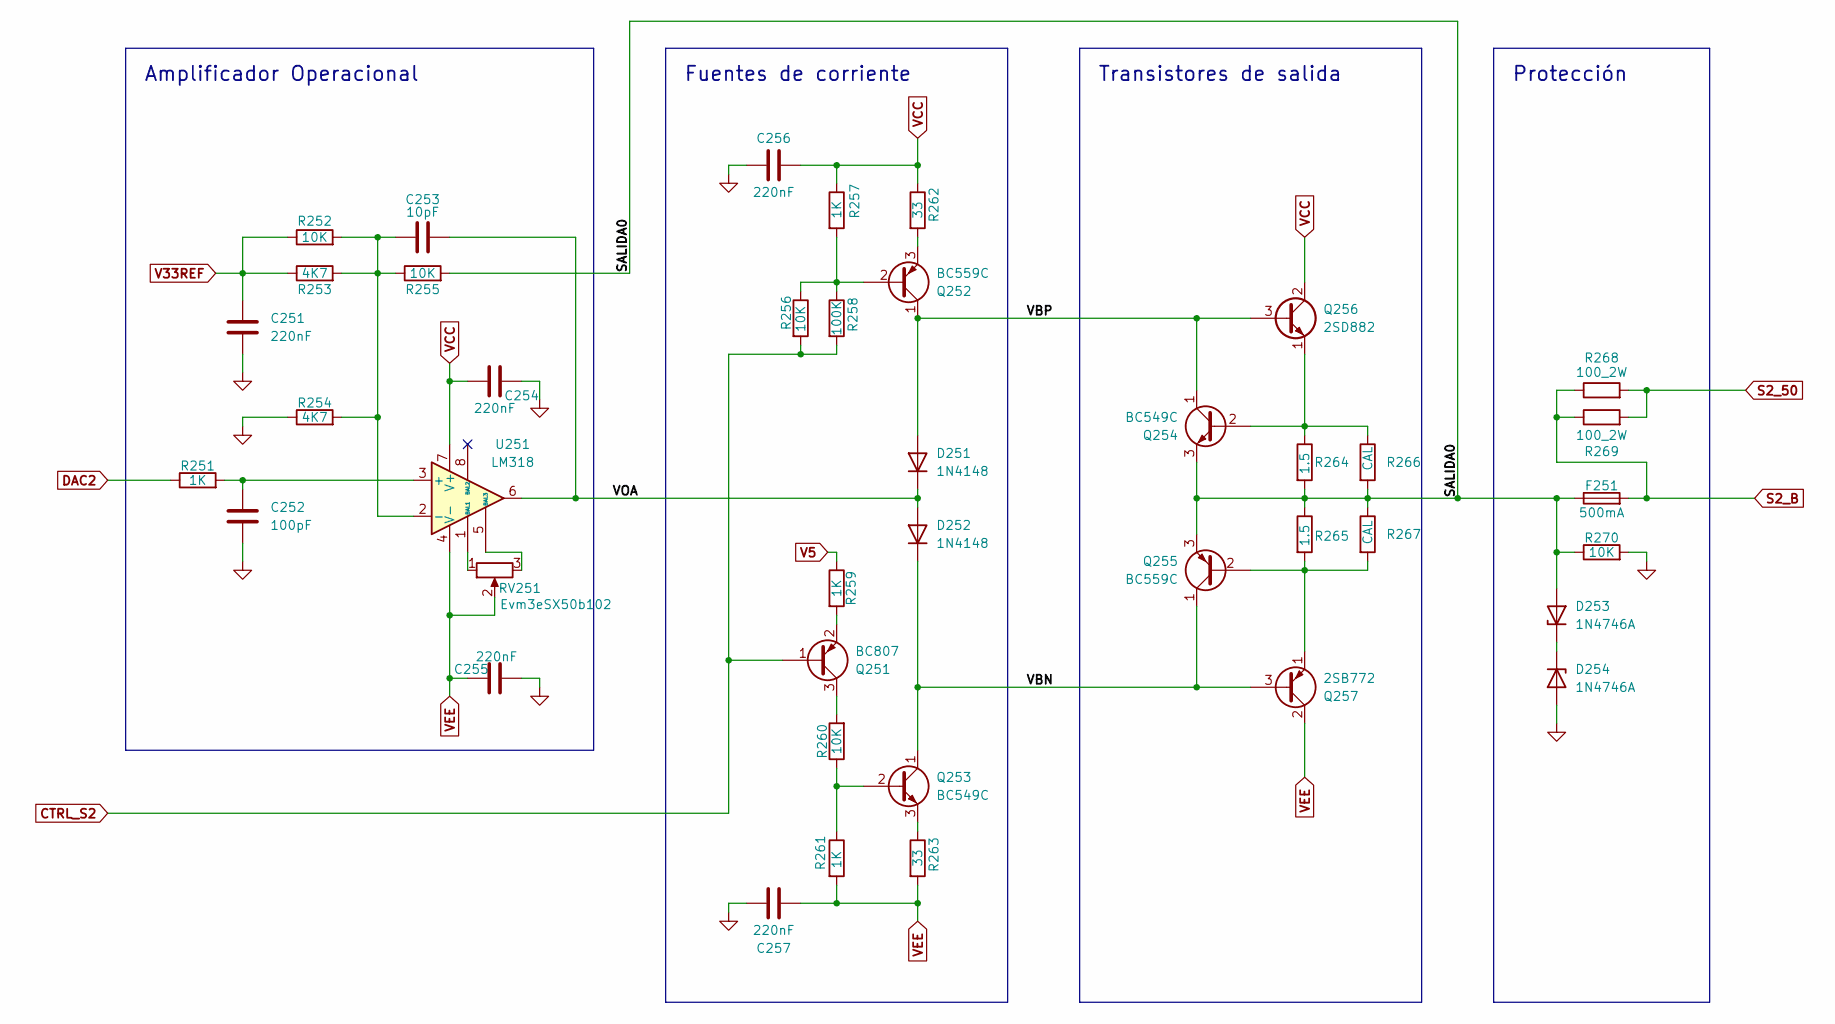
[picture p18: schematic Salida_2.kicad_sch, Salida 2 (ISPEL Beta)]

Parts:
C251, C254, C255, C256, C257: 220nF; C_1206_3216Metric_Pad1.33x1.80mm_HandSolder
C252: 100pF; C_1206_3216Metric_Pad1.33x1.80mm_HandSolder
C253: 10pF; C_1206_3216Metric_Pad1.33x1.80mm_HandSolder
D251, D252: 1N4148; D_MiniMELF_Handsoldering
D253, D254: 1N4746A; D_DO-41_SOD81_P10.16mm_Horizontal
F251: 500mA; Fuseholder_1808_handsoldering
Q251: BC807; SOT-23
Q252, Q255: BC559C; TO-92_Inline
Q253, Q254: BC549C; TO-92_Inline
Q256: 2SD882; TO-126-3_Vertical
Q257: 2SB772; TO-126-3_Vertical
R251, R257, R259, R261: 1K; R_1206_3216Metric_Pad1.30x1.75mm_HandSolder
R252, R255, R256, R260, R270: 10K; R_1206_3216Metric_Pad1.30x1.75mm_HandSolder
R253, R254: 4K7; R_1206_3216Metric_Pad1.30x1.75mm_HandSolder
R258: 100K; R_1206_3216Metric_Pad1.30x1.75mm_HandSolder
R262, R263: 33; R_1206_3216Metric_Pad1.30x1.75mm_HandSolder
R264, R265: 1.5; R_Axial_DIN0309_L9.0mm_D3.2mm_P12.70mm_Horizontal
R266, R267: CAL; R_1206_3216Metric_Pad1.30x1.75mm_HandSolder
R268, R269: 100_2W; R_Axial_DIN0414_L11.9mm_D4.5mm_P15.24mm_Horizontal
RV251: Evm3eSX50b102; 3E-SX50
U251: LM318; CERDIP-8_W7.62mm_SideBrazed_LongPads_Socket

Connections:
/Salida 2/SALIDA0: D253.2 (A), F251.1, Q254.3 (E), Q255.3 (E), R255.2, R264.2, R265.1, R266.2, R267.1, R270.1
/Salida 2/VBN: D252.1 (K), Q253.1 (C), Q255.1 (C), Q257.3 (B)
/Salida 2/VBP: D251.2 (A), Q252.1 (C), Q254.1 (C), Q256.3 (B)
/Salida 2/VOA: C253.2, D251.1 (K), D252.2 (A), U251.6
CTRL_S2: Q251.1 (B), R256.2, R258.2; also elsewhere on the board
DAC2: R251.1; also elsewhere on the board
GND: C251.2, C252.2, C254.1, C255.2, C256.2, C257.1, D254.2 (A), R254.1, R270.2; also elsewhere on the board
unnamed: D253.1 (K), D254.1 (K)
unnamed: Q251.3 (C), R260.2
unnamed: Q251.2 (E), R259.2
unnamed: Q252.2 (B), R256.1, R257.2, R258.1
unnamed: Q252.3 (E), R262.2
unnamed: Q253.2 (B), R260.1, R261.1
unnamed: Q253.3 (E), R263.1
unnamed: Q254.2 (B), Q256.1 (E), R264.1, R266.1
unnamed: Q255.2 (B), Q257.1 (E), R265.2, R267.2
unnamed: C252.1, R251.2, U251.3 (+)
unnamed: C253.1, R252.2, R253.2, R254.2, R255.1, U251.2 (-)
unnamed: RV251.1, U251.1 (BAL1)
unnamed: RV251.3, U251.5 (BAL3)
S2_50: R268.2, R269.2; also elsewhere on the board
S2_B: F251.2, R268.1, R269.1; also elsewhere on the board
V5: R259.1; also elsewhere on the board
V33REF: C251.1, R252.1, R253.1; also elsewhere on the board
VCC: C254.2, C256.1, Q256.2 (C), R257.1, R262.1, U251.7 (V+); also elsewhere on the board
VEE: C255.1, C257.2, Q257.2 (C), R261.2, R263.2, RV251.2, U251.4 (V-); also elsewhere on the board

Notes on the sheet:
Protección
Fuentes de corriente
Amplificador Operacional
Transistores de salida

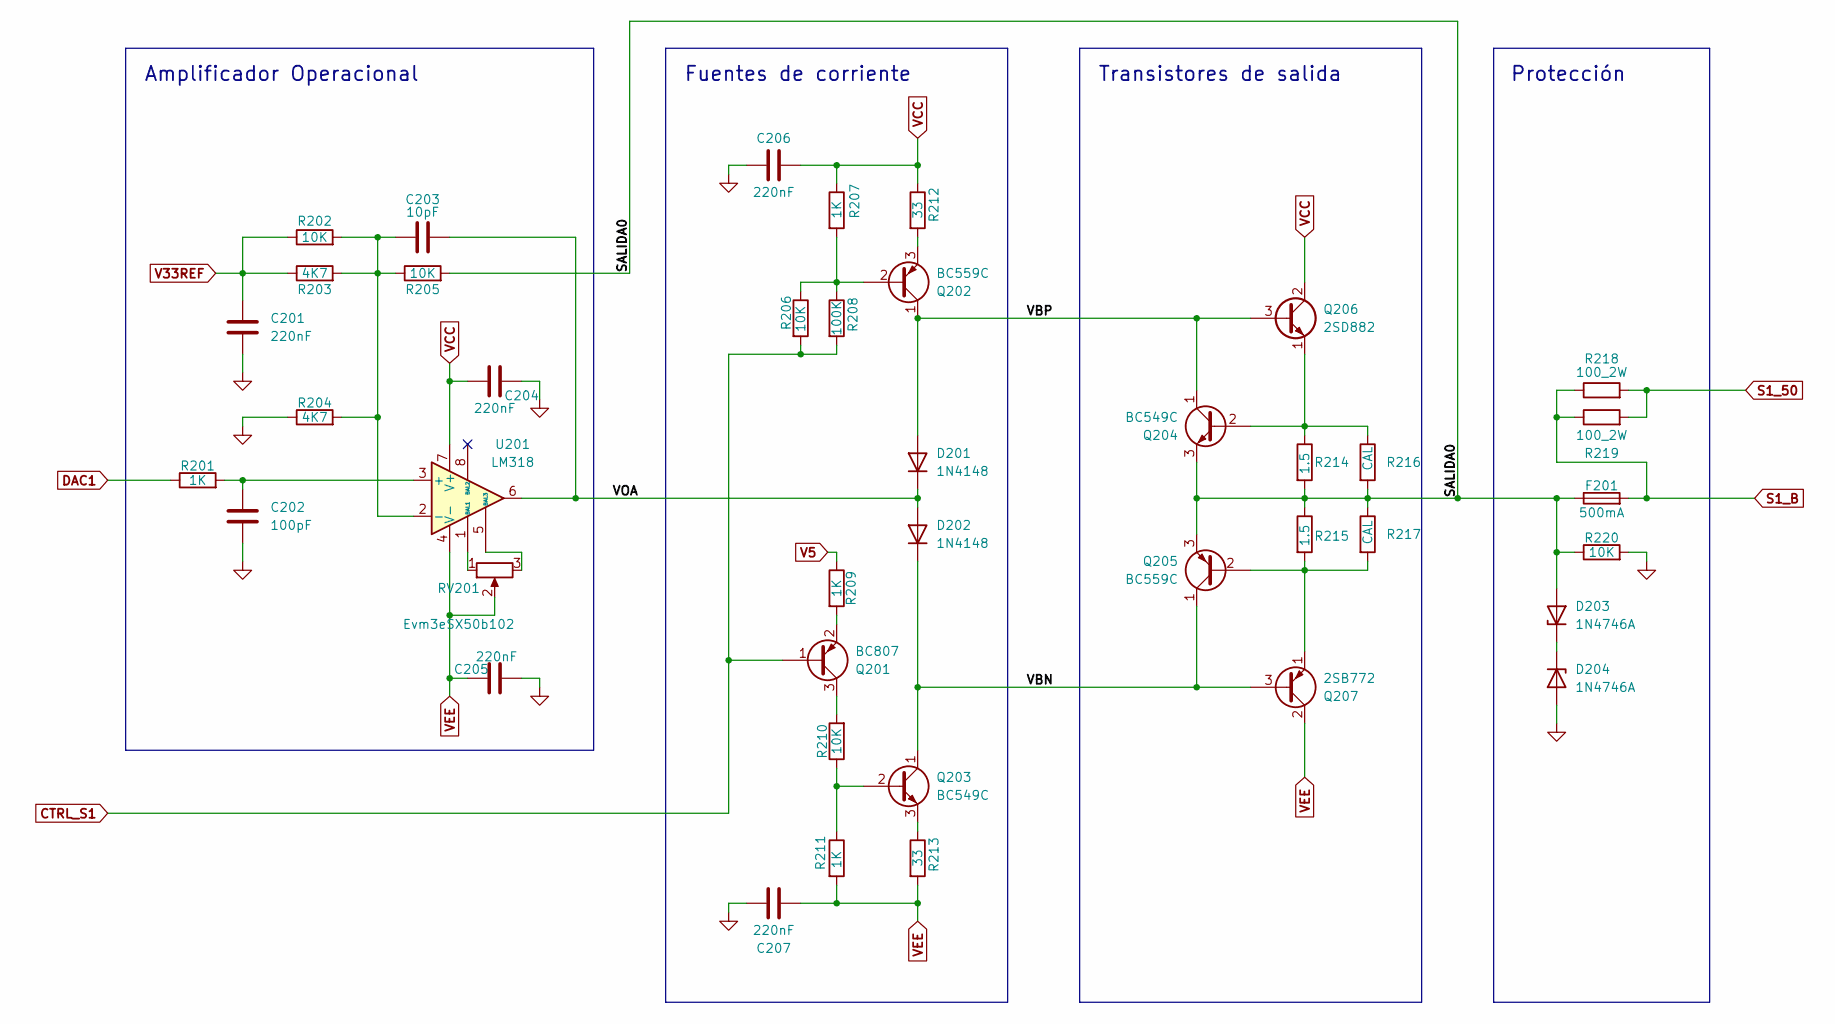
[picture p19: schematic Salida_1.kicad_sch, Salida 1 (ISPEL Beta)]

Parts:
C201, C204, C205, C206, C207: 220nF; C_1206_3216Metric_Pad1.33x1.80mm_HandSolder
C202: 100pF; C_1206_3216Metric_Pad1.33x1.80mm_HandSolder
C203: 10pF; C_1206_3216Metric_Pad1.33x1.80mm_HandSolder
D201, D202: 1N4148; D_MiniMELF_Handsoldering
D203, D204: 1N4746A; D_DO-41_SOD81_P10.16mm_Horizontal
F201: 500mA; Fuseholder_1808_handsoldering
Q201: BC807; SOT-23
Q202, Q205: BC559C; TO-92_Inline
Q203, Q204: BC549C; TO-92_Inline
Q206: 2SD882; TO-126-3_Vertical
Q207: 2SB772; TO-126-3_Vertical
R201, R207, R209, R211: 1K; R_1206_3216Metric_Pad1.30x1.75mm_HandSolder
R202, R205, R206, R210, R220: 10K; R_1206_3216Metric_Pad1.30x1.75mm_HandSolder
R203, R204: 4K7; R_1206_3216Metric_Pad1.30x1.75mm_HandSolder
R208: 100K; R_1206_3216Metric_Pad1.30x1.75mm_HandSolder
R212, R213: 33; R_1206_3216Metric_Pad1.30x1.75mm_HandSolder
R214, R215: 1.5; R_Axial_DIN0309_L9.0mm_D3.2mm_P12.70mm_Horizontal
R216, R217: CAL; R_1206_3216Metric_Pad1.30x1.75mm_HandSolder
R218, R219: 100_2W; R_Axial_DIN0414_L11.9mm_D4.5mm_P15.24mm_Horizontal
RV201: Evm3eSX50b102; 3E-SX50
U201: LM318; CERDIP-8_W7.62mm_SideBrazed_LongPads_Socket

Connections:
/Salida 1/SALIDA0: D203.2 (A), F201.1, Q204.3 (E), Q205.3 (E), R205.2, R214.2, R215.1, R216.2, R217.1, R220.1
/Salida 1/VBN: D202.1 (K), Q203.1 (C), Q205.1 (C), Q207.3 (B)
/Salida 1/VBP: D201.2 (A), Q202.1 (C), Q204.1 (C), Q206.3 (B)
/Salida 1/VOA: C203.2, D201.1 (K), D202.2 (A), U201.6
CTRL_S1: Q201.1 (B), R206.2, R208.2; also elsewhere on the board
DAC1: R201.1; also elsewhere on the board
GND: C201.2, C202.2, C204.1, C205.2, C206.2, C207.1, D204.2 (A), R204.1, R220.2; also elsewhere on the board
unnamed: D203.1 (K), D204.1 (K)
unnamed: Q201.3 (C), R210.2
unnamed: Q201.2 (E), R209.2
unnamed: Q202.2 (B), R206.1, R207.2, R208.1
unnamed: Q202.3 (E), R212.2
unnamed: Q203.2 (B), R210.1, R211.1
unnamed: Q203.3 (E), R213.1
unnamed: Q204.2 (B), Q206.1 (E), R214.1, R216.1
unnamed: Q205.2 (B), Q207.1 (E), R215.2, R217.2
unnamed: C202.1, R201.2, U201.3 (+)
unnamed: C203.1, R202.2, R203.2, R204.2, R205.1, U201.2 (-)
unnamed: RV201.1, U201.1 (BAL1)
unnamed: RV201.3, U201.5 (BAL3)
S1_50: R218.2, R219.2; also elsewhere on the board
S1_B: F201.2, R218.1, R219.1; also elsewhere on the board
V5: R209.1; also elsewhere on the board
V33REF: C201.1, R202.1, R203.1; also elsewhere on the board
VCC: C204.2, C206.1, Q206.2 (C), R207.1, R212.1, U201.7 (V+); also elsewhere on the board
VEE: C205.1, C207.2, Q207.2 (C), R211.2, R213.2, RV201.2, U201.4 (V-); also elsewhere on the board

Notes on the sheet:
Protección
Fuentes de corriente
Amplificador Operacional
Transistores de salida

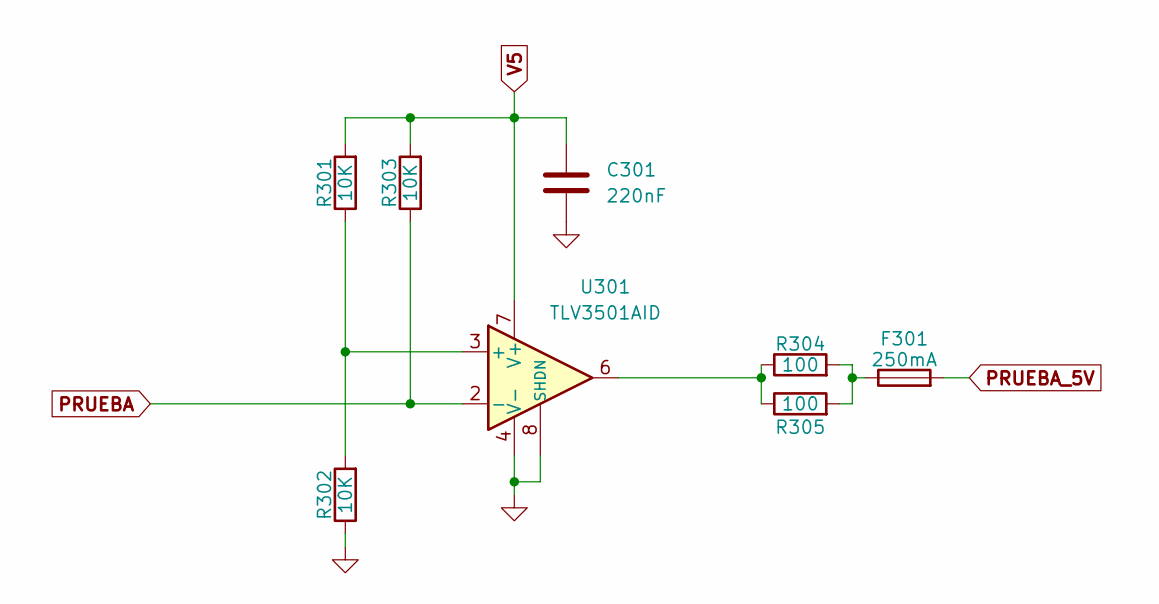
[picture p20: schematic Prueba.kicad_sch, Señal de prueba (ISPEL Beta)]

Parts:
C301: 220nF; C_1206_3216Metric_Pad1.33x1.80mm_HandSolder
F301: 250mA; Fuseholder_1808_handsoldering
R301, R302, R303: 10K; R_1206_3216Metric_Pad1.30x1.75mm_HandSolder
R304, R305: 100; R_1206_3216Metric_Pad1.30x1.75mm_HandSolder
U301: TLV3501AID; SOIC-8_3.9x4.9mm_P1.27mm

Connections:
GND: C301.1, R302.1, U301.4 (V-), U301.8 (SHDN); also elsewhere on the board
unnamed: F301.1, R304.2, R305.2
unnamed: R304.1, R305.1, U301.6
unnamed: R301.1, R302.2, U301.3 (+)
PRUEBA: R303.1, U301.2 (-); also elsewhere on the board
PRUEBA_5V: F301.2; also elsewhere on the board
V5: C301.2, R301.2, R303.2, U301.7 (V+); also elsewhere on the board

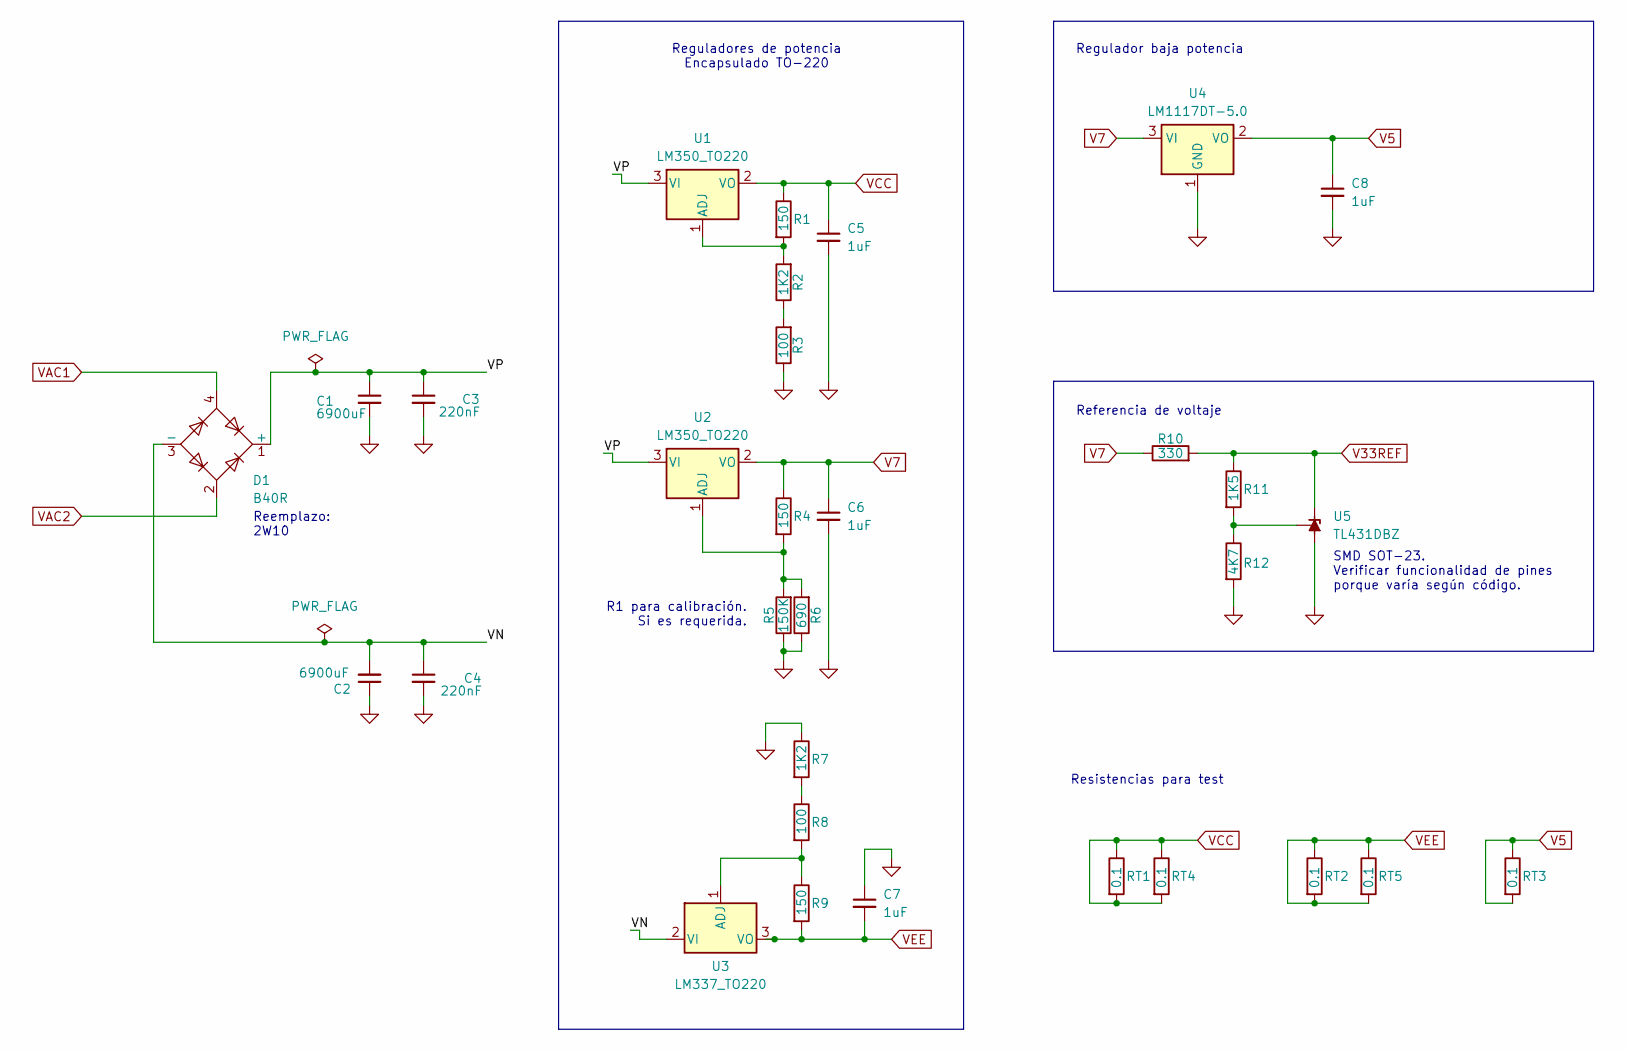
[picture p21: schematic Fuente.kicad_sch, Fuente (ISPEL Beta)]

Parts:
C1, C2: 6900uF; CP_Radial_D18.0mm_P7.50mm
C3, C4: 220nF; C_1206_3216Metric_Pad1.33x1.80mm_HandSolder
C5, C6, C7, C8: 1uF; C_1206_3216Metric_Pad1.33x1.80mm_HandSolder
D1: B40R; Diode_Bridge_Round_D9.0mm
R1, R4, R9: 150; R_1206_3216Metric_Pad1.30x1.75mm_HandSolder
R2, R7: 1K2; R_1206_3216Metric_Pad1.30x1.75mm_HandSolder
R3, R8: 100; R_1206_3216Metric_Pad1.30x1.75mm_HandSolder
R5: 150K; R_1206_3216Metric_Pad1.30x1.75mm_HandSolder
R6: 690; R_1206_3216Metric_Pad1.30x1.75mm_HandSolder
R10: 330; R_1206_3216Metric_Pad1.30x1.75mm_HandSolder
R11: 1K5; R_1206_3216Metric_Pad1.30x1.75mm_HandSolder
R12: 4K7; R_1206_3216Metric_Pad1.30x1.75mm_HandSolder
RT1, RT2, RT3, RT4, RT5: 0.1; R_1206_3216Metric_Pad1.30x1.75mm_HandSolder
U1, U2: LM350_TO220; TO-220-3_Vertical
U3: LM337_TO220; TO-220-3_Vertical
U4: LM1117DT-5.0; TO-252-3_TabPin2
U5: TL431DBZ; SOT-23

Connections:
/Fuente/VN: C2.2, C4.1, D1.3 (-), U3.2 (VI)
/Fuente/VP: C1.1, C3.1, D1.1 (+), U1.3 (VI), U2.3 (VI)
GND: C1.2, C2.1, C3.2, C4.2, C5.2, C6.2, C7.1, C8.2, R3.1, R5.1, R6.1, R7.1, R12.2, U4.1 (GND), U5.3 (A); also elsewhere on the board
unnamed: R2.1, R3.2
unnamed: R7.2, R8.1
unnamed: R1.2, R2.2, U1.1 (ADJ)
unnamed: R4.2, R5.2, R6.2, U2.1 (ADJ)
unnamed: R8.2, R9.1, U3.1 (ADJ)
unnamed: R11.2, R12.1, U5.2 (REF)
V5: C8.1, RT3.1, RT3.2, U4.2 (VO); also elsewhere on the board
V7: C6.1, R4.1, R10.1, U2.2 (VO), U4.3 (VI); also elsewhere on the board
V33REF: R10.2, R11.1, U5.1 (K); also elsewhere on the board
VAC1: D1.4; also elsewhere on the board
VAC2: D1.2; also elsewhere on the board
VCC: C5.1, R1.1, RT1.1, RT1.2, RT4.1, RT4.2, U1.2 (VO); also elsewhere on the board
VEE: C7.2, R9.2, RT2.1, RT2.2, RT5.1, RT5.2, U3.3 (VO); also elsewhere on the board

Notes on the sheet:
SMD SOT-23. Verificar funcionalidad de pines porque varía según código.
Reemplazo: 2W10
R1 para calibración. Si es requerida.
Referencia de voltaje
Reguladores de potencia Encapsulado TO-220
Resistencias para test
Regulador baja potencia

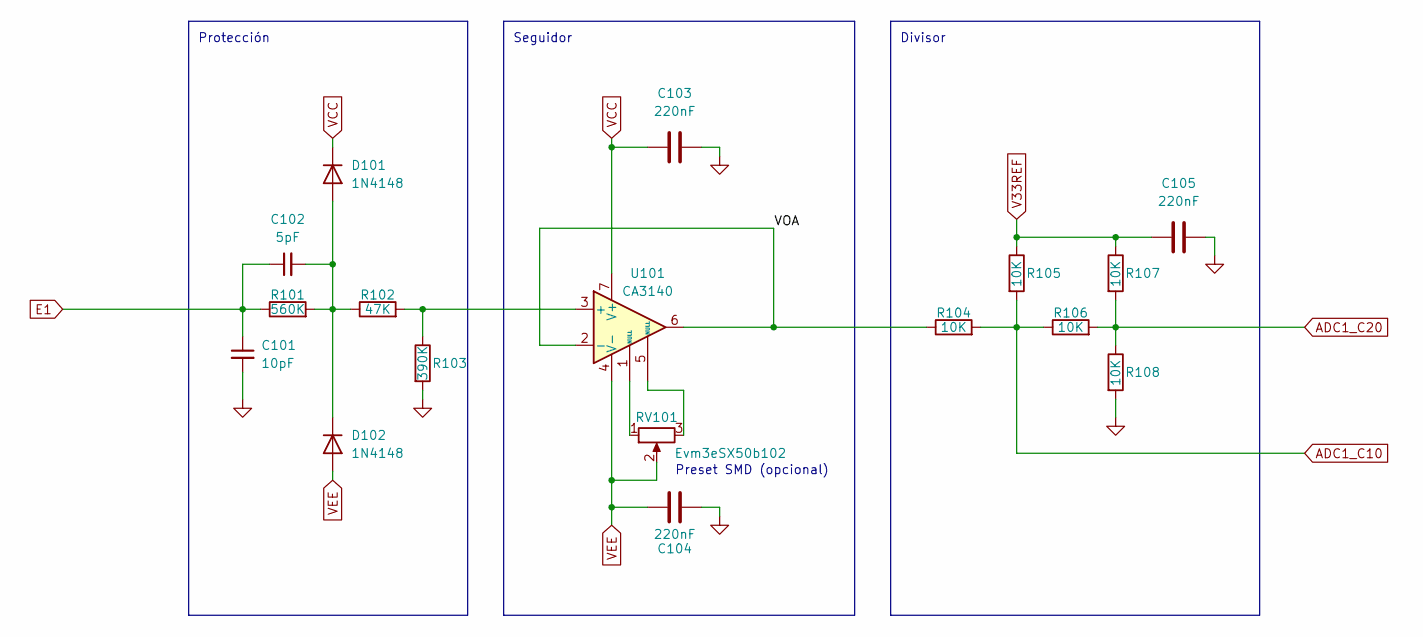
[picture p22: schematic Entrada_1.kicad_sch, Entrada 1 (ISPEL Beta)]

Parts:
C101: 10pF; C_1206_3216Metric_Pad1.33x1.80mm_HandSolder
C102: 5pF; C_1206_3216Metric_Pad1.33x1.80mm_HandSolder
C103, C104, C105: 220nF; C_1206_3216Metric_Pad1.33x1.80mm_HandSolder
D101, D102: 1N4148; D_MiniMELF_Handsoldering
R101: 560K; R_1206_3216Metric_Pad1.30x1.75mm_HandSolder
R102: 47K; R_1206_3216Metric_Pad1.30x1.75mm_HandSolder
R103: 390K; R_1206_3216Metric_Pad1.30x1.75mm_HandSolder
R104, R105, R106, R107, R108: 10K; R_1206_3216Metric_Pad1.30x1.75mm_HandSolder
RV101: Evm3eSX50b102; 3E-SX50
U101: CA3140; CERDIP-8_W7.62mm_SideBrazed_LongPads_Socket

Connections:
/Entrada 1/VOA: R104.1, U101.2 (-), U101.6
ADC1_C10: R104.2, R105.2, R106.1; also elsewhere on the board
ADC1_C20: R106.2, R107.2, R108.1; also elsewhere on the board
E1: C101.1, C102.1, R101.1; also elsewhere on the board
GND: C101.2, C103.2, C104.2, C105.2, R103.2, R108.2; also elsewhere on the board
unnamed: C102.2, D101.2 (A), D102.1 (K), R101.2, R102.1
unnamed: RV101.1, U101.1 (NULL)
unnamed: RV101.3, U101.5 (NULL)
unnamed: R102.2, R103.1, U101.3 (+)
V33REF: C105.1, R105.1, R107.1; also elsewhere on the board
VCC: C103.1, D101.1 (K), U101.7 (V+); also elsewhere on the board
VEE: C104.1, D102.2 (A), RV101.2, U101.4 (V-); also elsewhere on the board

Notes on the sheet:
Preset SMD (opcional)
Protección
Divisor
Seguidor

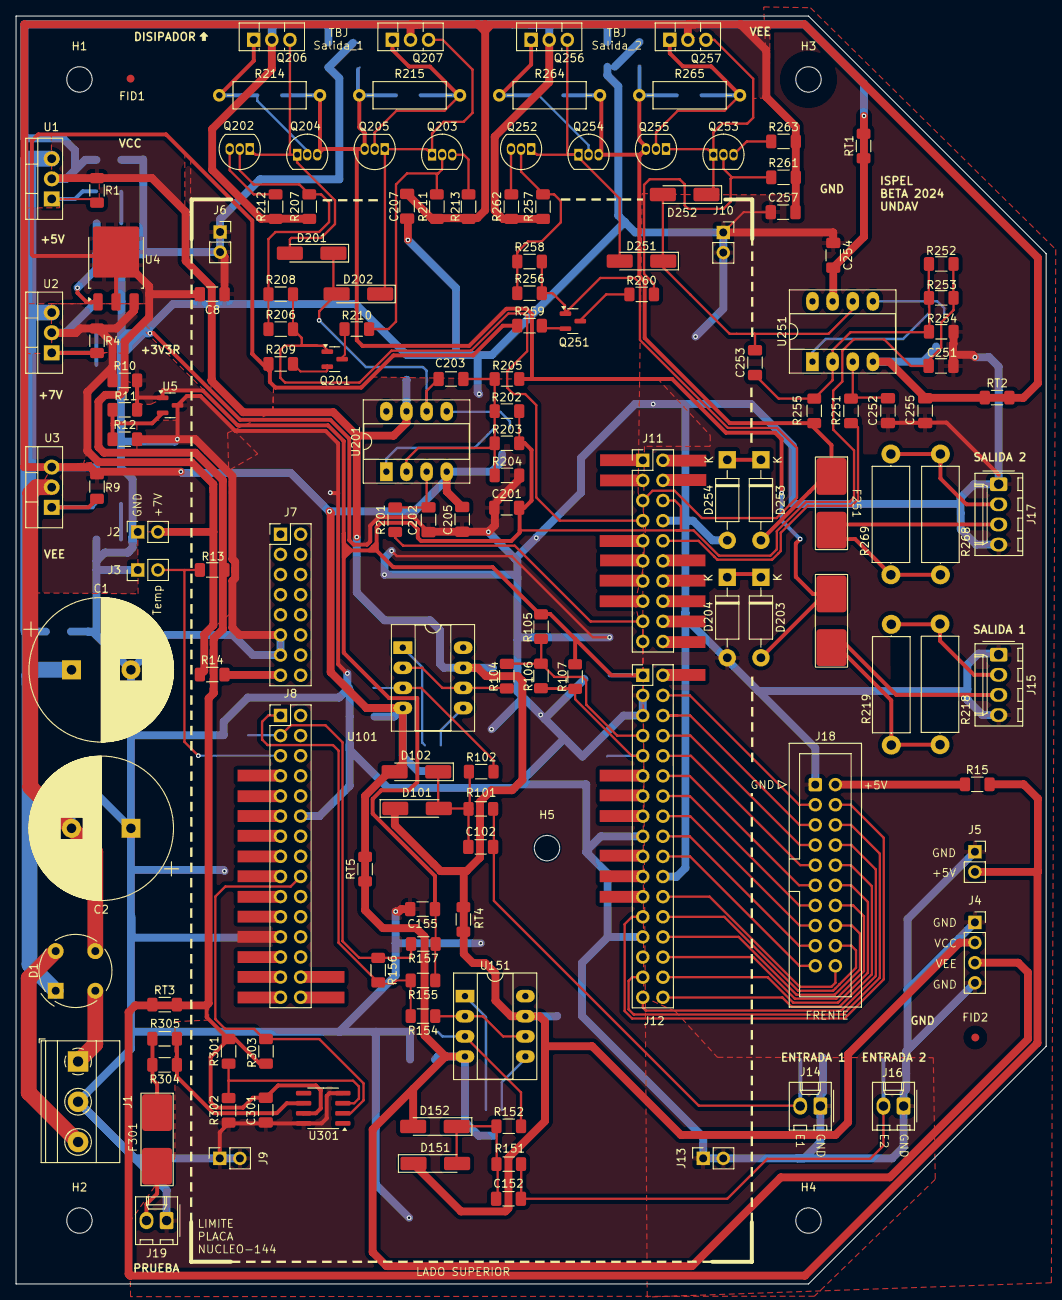
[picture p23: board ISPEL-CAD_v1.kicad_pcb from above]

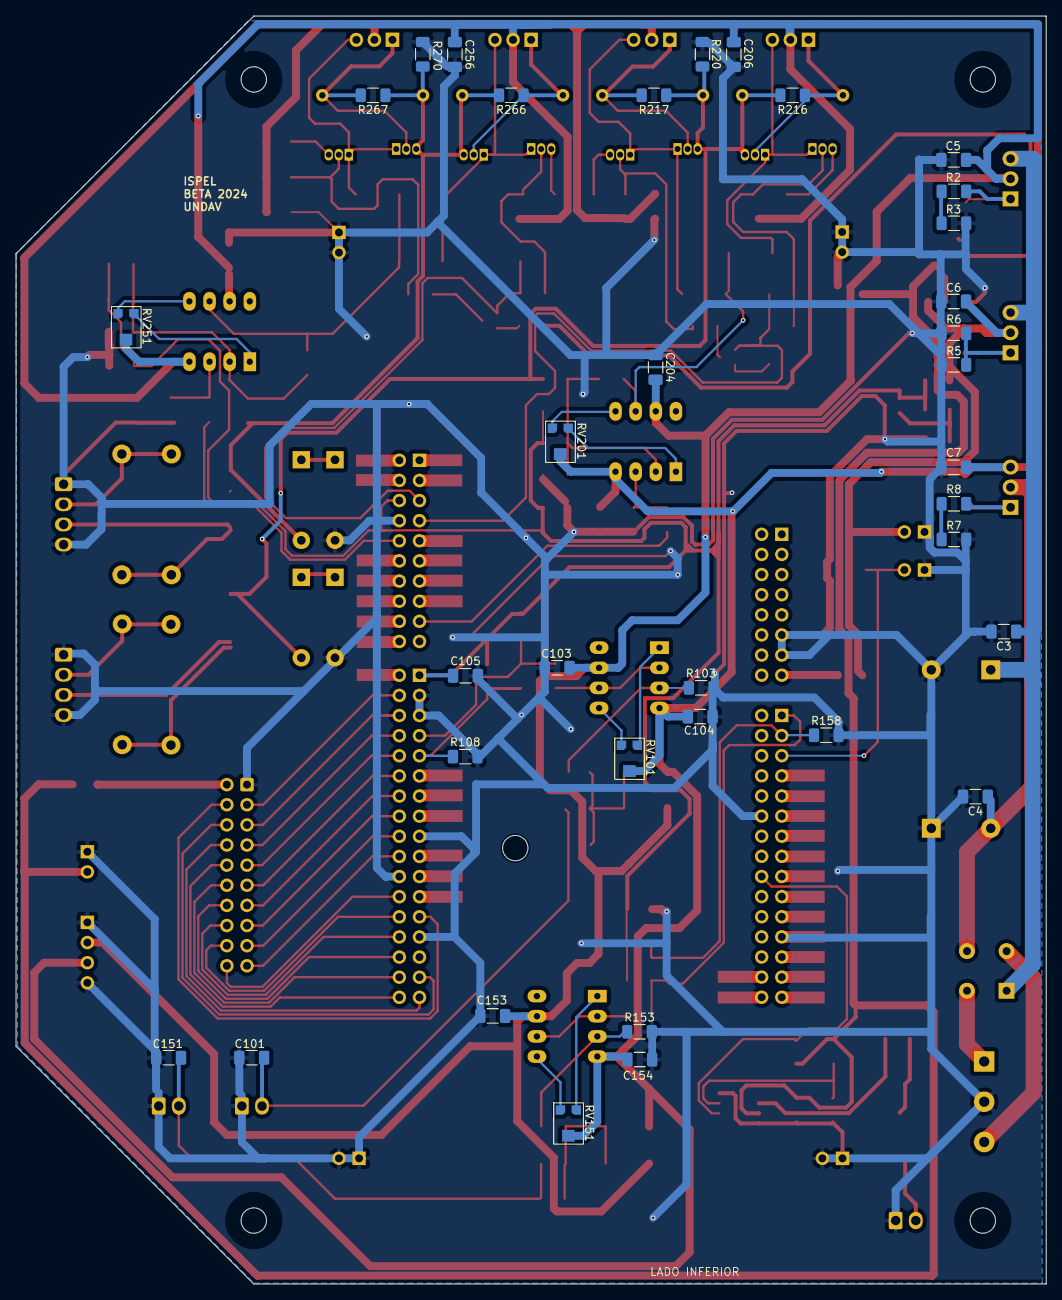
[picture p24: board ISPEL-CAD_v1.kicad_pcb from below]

Board: 2 copper layers, 130.0 x 160.0 mm, 184 parts (35 on the bottom side), 100 nets.

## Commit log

2024-07-17 Archivos y directorios iniciales.
    [frente_gabinete_v1_circuito.dxf]
2024-07-28 Empiezo a incluir documentación para PCB principal.
    [frente_gabinete_v1_circuito.dxf, frente_gabinete_v3_circuito.dxf]
2024-07-28 Primera versión de doc para diseño de PCB de amplificador.
2024-07-31 Primera versión con Arquitectura y Detalle de Diseño para PCB.
2024-08-04 Unificamos nombres de nodos y agregamos circuito de señal de prueba.
2024-10-04 Modificación en búfer de entrada.
2024-10-28 Versión 1 de esquemático, por AS.
    [AMPOP.kicad_sch, Buffer.kicad_sch, Buffer2.kicad_sch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]
2024-10-30 Versión 2 de esquemático, por GC.
    [AMPOP.kicad_sch, Buffer.kicad_sch, Buffer2.kicad_sch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]
2024-11-02 Iniciando PCB...
    [Entrada_1.kicad_sch, Entrada_2.kicad_sch, Fuente.kicad_sch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]
2024-11-08 Placa con conector J8.
    [Entrada_1.kicad_sch, Entrada_2.kicad_sch, ISPEL-CAD_v1.kicad_pcb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]
2024-11-08 Placa PCB con ERC. Falta huella de portafusibles.
    [ISPEL-CAD_v1.kicad_pcb, ISPEL-CAD_v1.kicad_sch, Salida_1.kicad_sch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]
2024-11-12 PCB con huella de portafusibles 1808.
    [ISPEL-CAD_v1.kicad_pcb, ISPEL-CAD_v1.kicad_sch, Prueba.kicad_sch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]
2024-11-13 Rellenos de blindaje.
    [ISPEL-CAD_v1.kicad_pcb]
2024-11-14 Corrección de conector.
    [ISPEL-CAD_v1.kicad_pcb, ISPEL-CAD_v1.kicad_sch, Listado de materiales ISPEL.xlsx]
2024-11-15 Corrigiendo hojas de datos.
    [ISPEL-CAD_v1.kicad_pcb]
2024-11-15 Actualización de hojas de datos.
    [Entrada_1.kicad_sch, Entrada_2.kicad_sch, ISPEL-CAD_v1.kicad_pcb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]
2024-11-17 Agregado de leyendas y pin para sensor de temperatura.
    [ISPEL-CAD_v1.kicad_pcb, ISPEL-CAD_v1.kicad_sch]
2024-11-29 Anotaciones para corregir placa x AS.
2024-11-30 Corrigiendo PCB con comentarios AS.
    [ISPEL-CAD_v1.kicad_pcb, Salida_1.kicad_sch, Salida_2.kicad_sch]
2024-12-02 Corrigiendo anotaciones.
    [Cálculos varios.xlsx, ISPEL-CAD_v1.kicad_pcb, ISPEL-CAD_v1.kicad_sch]
2024-12-03 Agregado de zócalo +7V y pruebas.
    [ISPEL-CAD_v1.kicad_pcb, ISPEL-CAD_v1.kicad_sch]
2024-12-03 Versión 1 - ISPEL Beta 2024 para fabricar.
    [Fuente.kicad_sch, ISPEL-CAD_v1.kicad_pcb, ISPEL-CAD_v1.kicad_sch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]
2024-12-03 Versión 1 - ISPEL Beta 2024 para fabricar (corregido).
    [ISPEL-CAD_v1.kicad_pcb, Listado de materiales ISPEL.xlsx]
2025-04-04 Agregado de hojas de datos.
2025-04-04 Revisión 1. Con prototipo ISPEL Beta 2024 en fase de prueba.
    [Entrada_1.kicad_sch, Entrada_2.kicad_sch, Fuente.kicad_sch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]
2025-04-04 Actualización de documentos e informes.
    [Cálculos varios.xlsx, Listado de materiales ISPEL.xlsx]
2025-04-04 Actualización de documentación.
